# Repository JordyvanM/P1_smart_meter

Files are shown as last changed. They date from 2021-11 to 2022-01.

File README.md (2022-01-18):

# P1_smart_meter
This repository contains simulations, documentation and schematics on the P1 smart meter reader project.

# Table of Contents
## 1. [Simulations]
### ·[Two powersupply switching]
### ·[Opamp signal inverter]

## 2. [Documentation]
### ·[PVA Dutch] (plan of action)
### ·[Report]

## 3. [Software]

## 4. [PCB_project]

## 4. [Sources]
### [URLS]

[Two powersupply switching]: https://github.com/JordyvanM/P1_smart_meter/blob/main/Simulations/Two_powersupply_switch.asc
[Opamp signal inverter]: https://github.com/JordyvanM/P1_smart_meter/blob/main/Simulations/V1_3.3_inverter.asc
[Simulations]: https://github.com/JordyvanM/P1_smart_meter/tree/main/Simulations

[Documentation]: https://github.com/JordyvanM/P1_smart_meter/tree/main/Documentation
[PVA Dutch]: https://github.com/JordyvanM/P1_smart_meter/tree/main/Documentation/PVA
[Report]: https://github.com/JordyvanM/P1_smart_meter/tree/main/Documentation/Report

[Software]: https://github.com/JordyvanM/P1_smart_meter/tree/main/Software

[PCB_project]: https://github.com/JordyvanM/P1_smart_meter/tree/main/PCB_project

[Sources]: https://github.com/JordyvanM/P1_smart_meter/tree/main/Sources
[URLS]: https://github.com/JordyvanM/P1_smart_meter/blob/main/Sources/URLS.md

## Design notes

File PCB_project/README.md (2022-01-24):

When the [.zip] file is opened it can be extracted and opend in Altium Designer. The [Smart meter case.3mf] file contains the 3D file for the case of the PCB. This file can be downloaded and for example 3D printed.

[.zip]: https://github.com/JordyvanM/P1_smart_meter/blob/main/PCB_project/slimme_meter_V4%20(17-1-2022%2016-21-46).zip
[Smart meter case.3mf]: https://github.com/JordyvanM/P1_smart_meter/blob/main/PCB_project/Smart%20meter%20case.3mf

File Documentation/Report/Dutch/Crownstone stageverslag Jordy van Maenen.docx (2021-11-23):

Stageverslag Jordy van Maenen

# Opdracht 1: Slimme meter

# 1. Onderzoek

## 1.1 Algemeen:

De eerste opdracht van Crownstone is het ontwerpen van een product dat aangesloten (en gevoed) kan worden gebruik makend van de P1 poort van een slimme meter. In de P1 poort van een slimme meter kan een stekker van het type RJ11 6P4C of 6P6C gestoken worden. Op pin 1 van deze poort staat +5V en pin 6 is de power_GND pin. De voeding kan een stroom leveren van maximaal 250mA continu wanneer de slimme meter gebaseerd is op DSMR (Dutch Smart Meter Requirements) 5 of hoger [1]. Wanneer de slimme meter gebaseerd is op DSMR 4 of ouder kan er maximaal 100mA continu gebruikt worden [2]. Bij DSMR 2 kan er helemaal geen gebruik gemaakt worden van voeding vanuit de P1 poort. Exacte aantallen zijn niet beschikbaar maar DSMR 5 lijkt op dit moment de meest gebruikte standaard gevolgd door DSMR 4 en DSMR 2. DSMR 5 en 4 lijken erg op elkaar doordat gebruikt gemaakt wordt van dezelfde baudrate, een start bit, 8 data bits, geen parity bit en een stop bit. Er zijn echter wel een aantal verschillen als het gaat om de frequentie waarmee de verschillende standaarden hun informatie sturen. DSMR 5 verstuurt alleen elke seconde alle data en verstuurt dan de laatste 5 minuten meting van het gasverbruik, het thermische gebruik en watergebruik. DSMR 4 verstuurt elke 10 minuten alle data en verstuurt dan de laatste uur meting van het gasverbruik, het thermische gebruik en watergebruik. DSMR 2 verstuurt ieder uur alle data. Voor het versturen van de data maakt de slimme meter gebruik van een open collector uitgang. Dit houdt in dat de uitgang of floating of verbonden met GND is. Om hiermee een goed signaal te maken is een pull-up weerstand nodig.

## 1.2 Connector:

Om gebruik te maken van deze poort moet er een stekker in gestoken worden van het type RJ11 6P4C of 6P6C. Voor dit project is er gekozen om de RJ11 6P6C connector te gebruiken (ook wel de RJ12 connector genoemd). Deze connector heeft 2 pinnen meer dan de standaard RJ11 connector waardoor er gebruik gemaakt kan worden van de voeding vanuit de P1 poort.

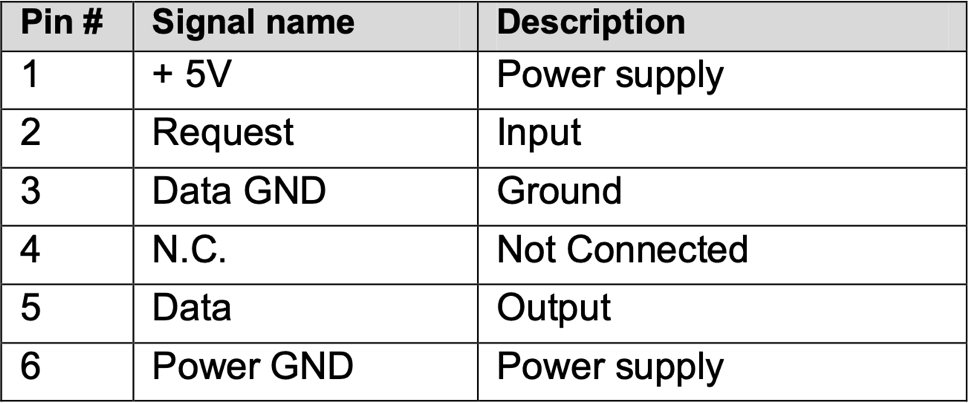
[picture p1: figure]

Figuur 1

In Figuur 1 is de pinout van de RJ12 connector weergegeven, deze tabel kan in de datasheets van DSMR 4 [2] en 5 [1] gevonden worden op pagina 6. Er mag maximaal 5mA de data pin in lopen. De voedingsspanning vanuit de P1 poort mag maximaal 5.5V zijn, om een maximale stroom van 5mA te realiseren is een weerstandswaarde van minimaal 5.5/5mA = 1100Ω nodig. De datalijn hoeft hoogstwaarschijnlijk geen 5mA te kunnen leveren om de rest van het circuit te laten functioneren dus is het handig om een nog hogere pull-up weerstand te gebruiken waardoor verliezen verminderd worden. Om de data overdracht te starten moet een spanning tussen de 4V en 5.5V op de request pin gezet worden.

## 1.3 Signaal P1 poort

Voor het ontwerp en het kiezen van een geschikte omvormer is het ook handig om te weten wat de maximale schakelsnelheid van het signaal uit de P1 poort is. Met een simpele schakeling bestaande uit een male RJ12 connector, een 6 kernige platte kabel, een pull-up weerstand en een prototypebordje kan dit onderzocht worden.

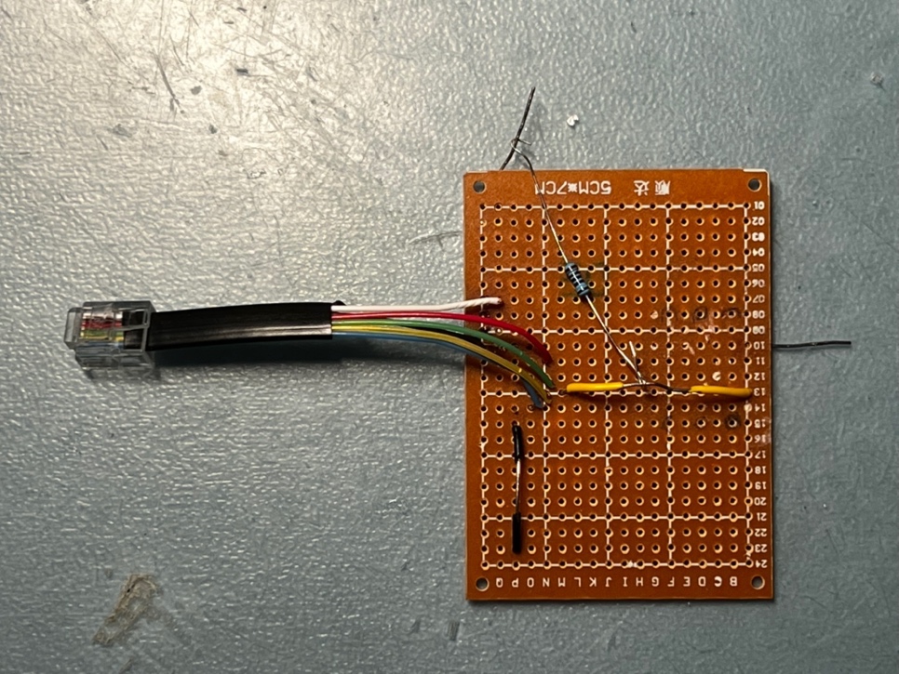
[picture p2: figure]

Figuur 2

Figuur 2 laat het ontworpen testbordje zien. De bovenste gestripte draad en de gestripte draad aan de rechterzijde moeten met elkaar verbonden worden om de dataoverdracht vanuit de P1 poort te starten. De gele in het midden gestripte draad is het meetpunt voor data pin 5. De zwarte in het midden gestripte draad is het GND punt. Dit bordje kan direct in de P1 poort van een slimme meter gestoken worden. Bij deze test is hij in een DSMR 5.0 meter gestoken om te onderzoeken wat de minimale puls duur is. Vervolgens is de probe van de oscilloscoop op de gele draad aangesloten en het GND punt op de zwarte draad. De oscilloscoop is aangezet en de twee volledig gestripte draden zijn met elkaar verbonden. Hierdoor werd op de oscilloscoop het signaal uit de P1 poort goed zichtbaar.

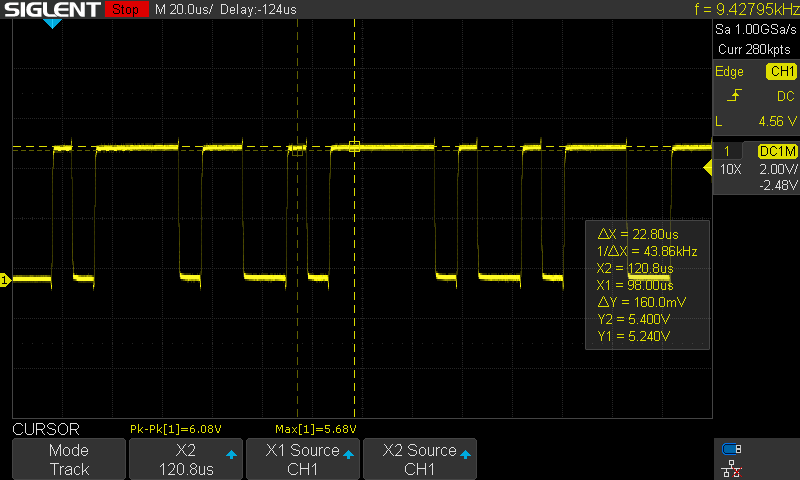
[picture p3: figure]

Figuur 3

Figuur 3 laat het signaal gemeten vanaf de half gestripte gele draad zien, dit is het signaal uit de P1 poort.

## 1.4 Omvormer

Het signaal uit de data pin is een geïnverteerd, te hoog maar voor de rest een voor de microcontroller leesbaar UART-signaal. Een hoge spanning (>1V, max 15V) is in dit geval dus een 0 en een lage spanning (<1V) is een 1. Om dit signaal leesbaar te maken voor de microcontroller moet het dus geïnverteerd en verlaagd worden tot maximaal 3.3V.

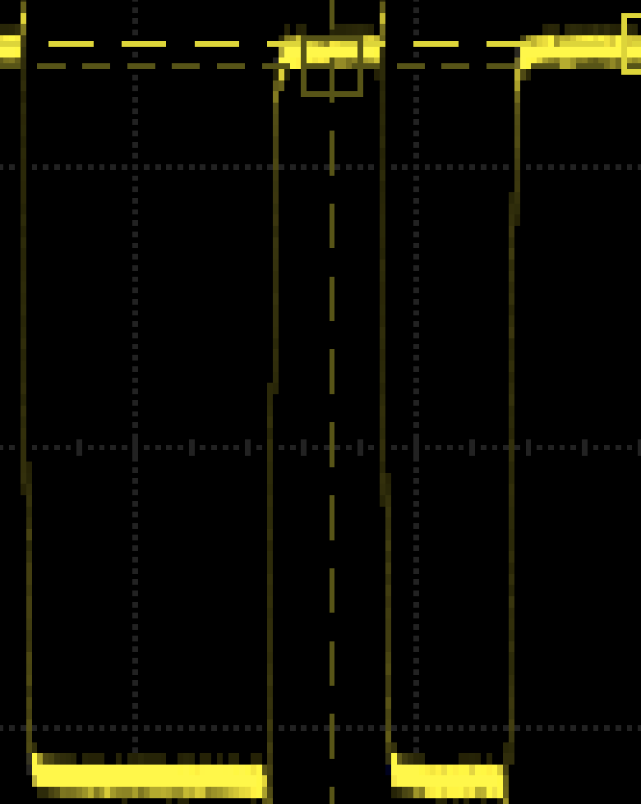
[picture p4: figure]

Figuur 4

Figuur 4 is een ingezoomd beeld van de kleinste puls duur uit Figuur 3. Deze puls duurt ongeveer 7.6us. Voor het kiezen van een geschikte omvormer is het van belang dat deze snel genoeg is om het signaal goed weer te kunnen geven. Om te bepalen welke slew rate nodig is om een signaal te krijgen waarvan maximaal 1/3 gebruikt wordt voor de rise en fall time zijn de volgende berekeningen nodig:

(7.6us)/6= 1.26us maximale rise time

(3.3v)/(1.26us)=2.62v/(us) minimale slew rate

Er is dus een minimale slew rate van 2.62 v/(us) nodig om een duidelijk signaal te behouden. Hier moet rekening mee gehouden worden wanneer de omvormer uitgekozen wordt.

## 1.5 Voeding

De voedingsspanning uit de P1 poort kan maximaal 5.5V en minimaal 4V zijn, over het algemeen is deze spanning 5V. Met het bordje in Figuur 2 is het ook mogelijk om de exacte voedingsspanning van de geteste slimme meter te meten.

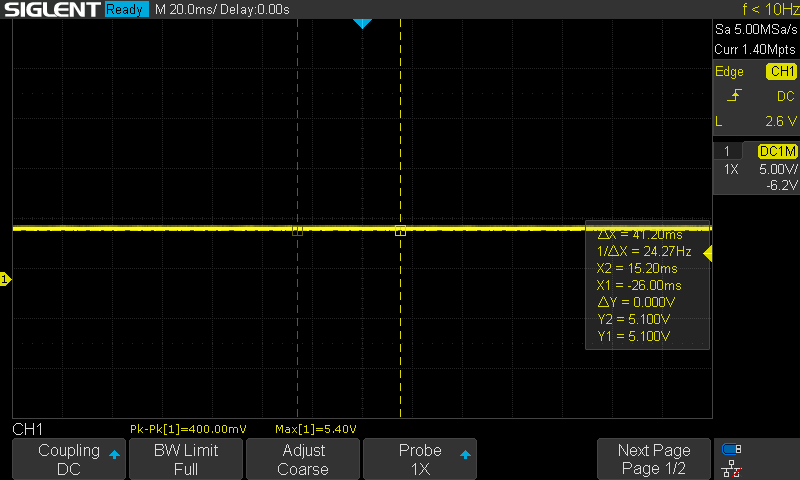
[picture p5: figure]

Figuur 5

Figuur 5 laat deze meting zien. Onderin is de maximaal gemeten spanning te zien, dit is 5.4V. Dit is waarschijnlijk een erg korte piek die door een storing van buitenaf komt. In het cursorvakje rechts in de afbeelding is Y2 en Y1 af te lezen. Dit zijn de gemeten spanningen op de cursors, beide zijn 5.1V. Deze meting laat zien dat de daadwerkelijke spanning erg in de buurt komt van de verwachtte 5V.

## 1.6 MCU

Voor de microcontroller unit zijn er verschillende mogelijkheden, er kan gebruik gemaakt worden van een kant en klare unit of van een eigen ontworpen schakeling met een losse NRF52832 chip. Een kant en klare module heeft als voordeel dat deze makkelijk te implementeren, al goedgekeurd en makkelijk te updaten is wanneer er een betere module beschikbaar komt. Het voordeel van een zelfontworpen schakeling is dat deze kleiner te maken is dan een kant en klare module en dat deze volledig aangepast kan worden aan de benodigdheden van het product. Daarnaast zijn de componentkosten lager zijn dan van een kant en klare module maar de ontwerpkosten hoger. Welk van de twee opties ook gekozen wordt, bij het ontwerp moet er aan een aantal zaken gedacht worden. Zo is er in het ontwerp een 32MHz oscillator en 32KHz oscillator nodig. Deze worden beide gebruikt voor timing in het huidige Crownstone product dus is het handig om deze ook in dit ontwerp te gebruiken. Verder moet er ook aan ontkoppelingscondensatoren gedacht worden. Deze zorgen ervoor dat de voedingsspanning geëgaliseerd wordt zodat de microcontroller geen instructies over gaat slaan of zich op een andere onverwachte manier gaat gedragen.

## 1.7 Software

Voor het verwerken van de informatie is ook goede software nodig. Het product moet idealiter kunnen werken met alle slimme meters die in gebruik zijn. Hierdoor zou het product aantrekkelijker zijn voor potentiele klanten omdat er niet nagedacht hoeft te worden of het apparaat wel geschikt is voor de gebruikte slimme meter. Dit zorgt alleen wel voor een aantal moeilijkheden. Zoals eerder beschreven zijn de verschillende standaarden wel degelijk verschillend van elkaar. Omdat bij DSMR 2 het voeden van externa apparaten door de P1 poort niet mogelijk is moet een manier gevonden worden om het product alsnog van voeding te zien willen de DSMR 2 meters ondersteund worden. Daarnaast moet het in software mogelijk gemaakt worden dat terwijl het programma draait de seriële instellingen vanzelf veranderd kunnen worden. Hierdoor zou de informatie uit DSMR 2 meters uitgelezen kunnen worden. Verder moet het programma ook in staat zijn om referentienummers te herkennen. Deze referentienummers geven aan wat de data die daarna komt betekent. Al deze referentienummers zijn te vinden in de DMSR 4 datasheet [2] en DSMR 5 datasheet [1]. De referentienummers gegeven in de datasheet zijn alle referentienummers, niet elke slimme meter gebruikt ze allemaal. Hierdoor moet het programma ook in staat zijn om nummers over te slaan wanneer deze niet gegeven worden. Bijvoorbeeld, een één fase slimme meter zal geen informatie geven over andere fasen dan degene waarop hij aangesloten zit.

## 1.8 Programma van eisen

Functionele eisen:

- Eis 1: Het eindproduct moet aangesloten kunnen worden op de P1 poort van een slimme meter.
- Eis 2: Het eindproduct moet gevoed kunnen worden door de P1 poort van een slimme meter.
- Eis 3: De actuele stroom en gasverbruik data uit deze poort dient verstuurd te worden via Bluetooth zodra deze ontvangen wordt vanuit de P1 poort.
- Eis 4: In het eindproduct dient er gebruik gemaakt te worden van de nRF52832 van Nordic Semi.
- Eis 5: Het eindproduct mag een maximale stroom van 100mA gebruiken.
- Eis 6: Het verbruik van meerdere fasen (indien aanwezig) moet individueel verzonden worden, het totaalverbruik kan dan op een aangesloten apparaat makkelijk berekend worden.
- Eis 7: Aan het begin van het bericht uit de P1 poort wordt een timestamp verstuurd. Deze dient door het eindproduct verzonden te worden.
- Eis 8: Het apparaat moet kunnen werken met slimme meters gebaseerd op Dutch Smart Meter Requirements (DSMR) 5, 4 en 2.

Niet functionele eisen:

- Eis 9: Het eindproduct moet zo goedkoop mogelijk uitgevoerd worden zonder dat andere eisen daaronder lijden.
- Eis 10: Het eindproduct moet zo klein mogelijk gemaakt worden zonder dat er op functionaliteit beperkt wordt.
- Eis 11: Het eindproduct moet via de SWD-pinnen geprogrammeerd kunnen worden.
- Eis 12: Het eindproduct moet UART gedebugd kunnen worden.

Verdere uitleg:

- Eis 1: Om ervoor te zorgen dat het eindproduct kan communiceren met de slimme meter moet het mogelijk zijn om het apparaat aan te sluiten op de slimme meter. Dit kan alleen door gebruik te maken van de P1 poort van de slimme meter.
- Eis 2: Slimme meters die gebruik maken van DSMR 4 of hoger kunnen externa apparaten voeden via de P1 poort. Het is handig om gebruik te maken van deze functie om het aansluiten van het eindproduct erg gemakkelijk te maken.
- Eis 3: Crownstone maakt in al haar producten gebruik van Bluetooth en ook dit eindproduct moet werken met Bluetooth zodat het geïntegreerd kan worden met de andere producten van Crownstone. De stroom en gasverbruik data is in het begin het meest interessant, hiermee kan al een goed inzicht verkregen worden in het energieverbruik. Extra informatie zoals standsverwarming en verkoeling of watergebruik kunnen later in software nog toegevoegd worden.
- Eis 4: Crownstone werkt op dit moment al met chips van Nordic Semi en onder andere ook de nRF52832. Voor het bedrijf is het daarom handig dat in dit eindproduct ook deze chip zit zodat de firmware van dit product geïntegreerd kan worden met de Bluenet firmware van Crownstone zelf. Deze firmware is te vinden op https://github.com/crownstone/bluenet.
- Eis 5: DSMR 5 en hoger kan tot 250mA maar in dit geval moet het stroomverbruik onder de 100mA blijven om ervoor te zorgen dat het eindproduct ook op meters gebaseerd op DSMR 4 werken zonder dat een externe voeding aangesloten hoeft te worden.
- Eis 6: Het verbruik van individuele fasen bekijken kan voor een gebruiker erg interessant zijn. Misschien worden de verschillende fasen bijvoorbeeld gebruikt voor verschillende delen van een gebouw, hier zou dan het verbruik van de verschillende delen van het gebouw gemonitord kunnen worden.
- Eis 7: Het is handig om de timestamp uit de P1 poort te versturen zodat het gemeten energieverbruik op het correcte tijdstip weergegeven wordt.
- Eis 8: Het is handig om het eindproduct te kunnen laten werken op vrijwel alle slimme meters in Nederland. Hierdoor hoeven potentiële klanten niet na te denken of het eindproduct wel of niet op hun slimme meter werkt.
- Eis 9: Voor het maken van dit prototype moet er nagedacht worden over de kosten. Het is niet de bedoeling dat er roekeloos materialen ingekocht worden terwijl er misschien met een klein beetje nadenken een goedkoper alternatief gevonden kan worden.
- Eis 10: Voor de gebruiker is het handig om dit product zo klein mogelijk te maken. Hierdoor zou het eindproduct makkelijker in krappe ruimtes geplaatst kunnen worden.
- Eis 11: De SWD pinnen op de nRF52832 zijn er om de nRF52832 te programmeren. Deze moeten makkelijk beschikbaar zijn voor het programmeren van de nRF52832.
- Eis 12: UART wordt door Crownstone gebruikt voor het debuggen. Het is handig om deze functie ook toe te voegen aan het te maken eindproduct zodat de programmeurs zo min mogelijk hoeven te veranderen in hun manier van programmeren.

# 1 Keuzes

Om dit product werkend te krijgen zijn er meerdere deelsystemen nodig. Een connector, een omvormer, een voeding en een MCU-module. Verder moeten er ook nog andere keuzes gemaakt worden die de werking van het product beïnvloeden.

## 2.1 Connector

Het product moet aangesloten kunnen worden op een slimme meter, dit gebeurt met een RJ12 (RJ11 6p6c) connector. Er kan gekozen worden om het product te voorzien van een RJ12 poort zodat er een male RJ12 naar male RJ12 kabeltje gebruikt kan worden. Een andere optie is om een kabel met aan één kant een male RJ12 stekker aan de andere kant vast te solderen op het product. Dit zou ervoor zorgen dat het product een stuk platter kan worden maar heeft als nadeel dat de productie meer kost en dat wanneer het kabeltje kapotgaat het hele product niet meer werkt.

Oplossing | Voordelen | Nadelen
RJ12 poort op PCB solderen | Goedkoop, voorkomt onnodig onbruikbaar raken van het product. | Maakt het ontwerp een stuk groter
RJ12 kabel op PCB solderen | Klein ontwerp | Duur, moeilijke assemblage

Figuur 6

Conclusie:

Er is voor gekozen om in het ontwerp gebruik te maken van de RJ12 poort op de PCB. Het ontwerp zal desondanks de grote connector erg klein blijven.

## 2.2 Omvormer

Een omvormer is nodig om ervoor te zorgen dat het te hoge en geïnverteerde UART-signaal leesbaar te maken voor de microcontroller. Hiervoor zijn verschillende opties mogelijk. Er kan gebruik gemaakt worden van een opamp. Hierbij zal 3.3 volt op de positieve voeding gezet worden en de negatieve kant van de voeding aan GND aangesloten worden. Op de positieve ingang zal 1.65V volt gezet worden en op de negatieve ingang zal het signaal vanuit de P1 poort gezet worden. De 1.65V zal behaald worden door gebruik te maken van twee weerstanden van 1MΩ en deze als spanningsdeler te laten fungeren. Hierdoor zal de uitgang van de opamp laag zijn wanneer het signaal uit de P1 poort hoger is dan 1.65 volt en 3.3 volt zijn wanneer het signaal uit de P1 poort lager is dan 1.65 volt.

Een andere optie is het gebruiken van een transistorschakeling. Hiermee zou de schakeling uit alleen transistoren en weerstanden bestaan. Dit heeft als voordeel dat het goedkoper in onderdelen is. Nadelen zijn alleen dat er actief een stroom in moet gaan lopen om een spanning te krijgen. In het ideale geval zou dit bij een opamp niet het geval zijn.

Oplossing | Voordelen | Nadelen
Opamp | Het is één component dat zowel de spanning verlaagt als inverteert. Makkelijk te fabriceren. Blijft snel schakelen 3.3V onder een load. | Duurder
Transistor en weerstanden | Goedkoop | Output komt niet bij GND. Gevoeliger voor temperatuur. Meer componenten dus meer solderen.

Figuur 7

Conclusie:

Er is gekozen om in het ontwerp gebruik te maken van een opamp. Hier is gemak en accuraatheid belangrijker.

## 2.3 Voeding

Een voeding zorgt ervoor dat de spanning die het product in gaat geschikt is om gebruikt te worden door de individuele componenten. Hiervoor zijn er meerdere opties beschikbaar, een LDO of een schakelende voeding. Een LDO heeft als voordeel dat het erg eenvoudig te implementeren is, zeker wanneer er gekozen wordt voor een LDO met een gefixeerde uitgangsspanning. Het nadeel van een LDO is dat er meer vermogen verspild wordt in de vorm van warmte dan bij een schakelende voeding. Een schakelende voeding heeft als voordeel dat hij erg zuinig is. Nadelen van een schakelende voeding zijn dat hij meer ruis veroorzaakt, lastiger te implementeren is en duurder is.

Oplossing | Voordelen | Nadelen
LDO | Makkelijk en goedkoop | Minder efficiënt
Schakelende voeding | Energiezuinig | Duurder, meer componenten, meer ruis.

Figuur 8

Conclusie:

Er is gekozen om in het ontwerp gebruik te maken van de LDO. Deze zijn wel minder efficiënt alleen het stroomverbruik van het gehele ontwerp zal minimaal zijn dus ook de verspilling.

## 2.4 MCU-module

De MCU-module is nodig om alle binnenkomende informatie te verwerken en daarop te reageren. Deze module moet programmeerbaar zijn zodat er eigen software op gezet kan worden. Als microcontroller wordt de NRF52832 gebruikt. Er zijn alleen verschillende manieren om deze microcontroller te implementeren, dit kan in de vorm van een kant en klare module of een zelfontworpen module. Het voordeel van een kant en klare module is dat deze makkelijk te implementeren zijn en makkelijk te vervangen zijn wanneer er van een andere microcontroller gebruikgemaakt wil worden. Het voordeel van een zelfontworpen module is dat de kosten van de componenten lager zijn en dat de schakeling op een eigen PCB erg klein gemaakt kan worden.

Oplossing | Voordelen | Nadelen
Kant en klare module | Makkelijk te implementeren, makkelijk te upgraden. | Prijs van de component ligt hoger dan de losse componenten van een zelfontworpen module.
Zelfontworpen module | Kan erg klein gemaakt worden, goedkoper in de ontwikkeling. | Het ontwerpen is lastig, tijdrovend en daardoor duur. Wanneer een nieuwe microcontroller uit komt moet de gehele pcb herontworpen worden.

Figuur 9

Conclusie:

Er is gekozen om in het ontwerp gebruik te maken van een kant en klare module. De aanschaf kosten worden uiteindelijk overschaduwd door de ontwerpkosten van een zelfontworpen module.

## 2.5 Wel of geen externe voeding nodig

Volgens de als eerst opgestelde eisen moet het te ontwerpen product in ieder geval gevoed kunnen worden vanuit de P1 poort. Na verder onderzoek is er alleen ontdekt dat oudere slimme meters niet de mogelijkheid hebben om externe apparatuur via de P1 poort te voeden. Deze oudere slimme meters worden in ieder geval niet meer geplaatst maar zijn nog wel in gebruik. Exacte hoeveelheden zijn ook via de energieleveranciers lastig te krijgen. Wanneer er in het ontwerp geen mogelijkheid meegenomen wordt om het product via bijvoorbeeld een micro USB-poort te voeden zullen de oudere slimme meters van DSMR-versie 2 of lager niet ondersteund worden.

Oplossing | Voordelen | Nadelen
Geen externe voedingsmogelijkheid | Makkelijker te ontwerpen, goedkoper in productie, makkelijker in code te implementeren | Het product zal niet op oudere slimme meters werken, werkt dan op minder slimme meters dan de concurrentie
Wel een externe voedingsmogelijkheid | De consument hoeft niet na te denken wat voor slimme meter er geïnstalleerd is | Hogere implementatiekosten, hogere productiekosten

Figuur 10

Conclusie:

Er is gekozen om in het ontwerp wel de mogelijkheid om het product extern te voeden toe te voegen. Hierdoor hoeft de consument niet na te denken of dit product wel in zijn of haar specifieke situatie werkt. Wanneer dit niet mogelijk zou zijn zou er een extra reden zijn om voor een concurrerend product te kiezen.

## 2.6 LED’s

Voor het geven van visuele indicatoren richting de gebruiker zijn LED’s erg handig. Met verschillende kleuren kan bijvoorbeeld aangegeven worden dat het product aan staat en dat er bijvoorbeeld dataoverdracht is. Er zijn alleen verschillende manieren om LED’s te implementeren. Er kan gekozen worden voor losse LED’s direct op de voedingsspanning en datalijn aangesloten met aan/uit controle van de microcontroller waarmee hardware matig aangegeven wordt dat het product aan staat en dat er dataoverdracht is. De microcontroller heeft op deze manier wel nog de controle of dat LED’s aan of uit staan maar deze kunnen niet snel geschakeld worden door middel van PWM. Een andere keuze is om een RGB LED op de microcontroller aan te sluiten en softwarematig statusindicatoren te geven. De eerste optie heeft als voordeel dat het erg makkelijk te implementeren en goedkoop is, het nadeel is alleen dat deze LED’s later niet een andere functie gegeven kan worden. De laatste optie heeft als voordeel dat de functie van de LED’s later nog veranderd kan worden, het nadeel is dat er iets meer code nodig is en dat er Mosfets nodig zijn om de LED’s te schakelen.

Oplossing | Voordelen | Nadelen
Losse LED’s direct op signaallijnen | Makkelijker te ontwerpen, goedkoper in productie, minimale hoeveelheid code nodig | De LED’s hebben maar één functie en die kan later ook niet aangepast worden
RGB LED met microcontroller aansturen | Softwarematig de functies aanpassen van de LED’s | Meer componenten nodig

Figuur 11

Conclusie:

Er is gekozen om een RGB-led met behulp van Mosfets op de microcontroller aan te sluiten. Het is iets duurder maar brengt wel veel meer mogelijkheden met zich mee.

# 3. Het ontwerp

## 3.1 Componentkeuze

Onderdeel | Componenten | Verschillen | Keuze
RJ12 connector | 1. Molex 95501-6669 [3] 2. Wurt Elektronik 615006138421 [4] | Optie 1 is beter leverbaar en compacter dan optie 2. | Er is gekozen om van optie 1 gebruik te maken in het uiteindelijke ontwerp.
Opamp | 1. TI TLV9101IDBVR [5] | Optie 1 heeft een rail-to-rail input en output en een slew-rate van 4.5V/µs. | Er is gekozen om van optie 1 gebruik te maken in het uiteindelijke ontwerp.
LDO | 1. TI TPS7A2533DRVR [6] 2. ST LDFM33PVR [7] 3. MT MCP1755S-3302E/MC [8] | Optie 1 heeft de laagste ruststroom van maar 2µA, is per 1000 stuks de één na goedkoopste maar de duurste in kleine hoeveelheden. Optie 2 is de goedkoopste per 1000 stuks en de één na goedkoopste in kleine hoeveelheden, deze heeft alleen de hoogste ruststroom van 200µA. Optie 3 is in kleine hoeveelheden het goedkoopst maar per 1000 stuks het duurste, deze zit op het gebied van ruststroom tussen de andere twee in met 68µA | Er is gekozen om van optie 1 gebruik te maken in het uiteindelijke ontwerp.
MCU-module | 1. Raytac MDBT42Q-512KV2 [9] 2. Aconno ACN52832 [10]

Figuur 12

- Voor de female RJ12 connector is er voor de 95501-6669 connector van Molex gekozen. Deze connector is uit voorraad leverbaar en is grotendeels SMD. Hierdoor kunnen er wanneer nodig meer componenten aan de onderkant geplaatst worden.
- Voor de als omvormer gebruikte opamp is er gekozen voor de TLV9101IDBVR van TI. Dit is een low power rail-to-rail opamp, hierdoor is de output zo dicht mogelijk bij 3.3V of GND.
- Voor de voeding is er gekozen voor een TPS7A2533DRVR van TI. Deze LDO heeft een Ultra-low quiescent current van 2 μA en een maximum dropout voltage van minder dan 340 mV bij 300 mA waardoor het een erg zuinige LDO is. Deze LDO geeft ook standaard 3.3V zonder dat daarvoor externe weerstanden nodig zijn. Dit scheelt ruimte op de PCB en kan de spanning niet kan veranderen door in temperatuur veranderende weerstanden.
- Voor de MCU-module is er gekozen voor een ACN52832 van Oconno. Deze module is goed voorradig, en is makkelijk te implementeren. Alle pinnen zitten aan de buitenkant wat het solderen en debuggen een stuk makkelijker maakt. Deze module is ook te vinden op de website van Nordic Semi [11].
- Als connector voor een externe voeding is er gekozen voor een micro-USB poort. Deze poort is wel al behoorlijk op leeftijd alleen ze zijn goedkoop om te implementeren en zijn er al veel geschikte kabels en adapters op de markt. USB geeft standaard ook een spanning van +5V, dit is dezelfde spanning als uit de P1 poort. Dit versimpelt het ontwerp ook ten opzichte van wanneer er een andere poort gekozen zou zijn.
- Er is gekozen om een 2x5 2.54mm smd footprint te gebruiken voor het debuggen. Deze connector wordt op dit moment ook op het hoofdproduct van Crownstone gebruikt voor het debuggen en programmeren. Het gebruiken van dezelfde connector maakt het debuggen en programmeren van het te ontwerpen product voor het bedrijf een stuk makkelijker.
- Voor de RGB-led is er gekozen voor de L1MC-RGB0035000MP0 van Lumileds. Deze RGB-led is goed uit voorraad leverbaar, is meer dan fel genoeg en goedkoop.

## 3.2 Ontwerp units

Hieronder zal uitgelegd worden hoe de hierboven benoemde componenten geïmplementeerd zullen worden in de verschillende units en waarom ze op die manier geïmplementeerd worden.

### 3.2.1 RJ12 connector

Pin 3(data_gnd) zal aan pin 6(power_gnd) verbonden worden, het is niet nodig dat de data een afzonderlijke ground heeft. Pin 4 is NC dus blijft floating. Pin 5 is de data pin, deze pin is een open collector uitgang. Om uit deze uitgang een nuttig signaal te krijgen is een pull-up weerstand nodig. Volgens hoofdstuk 4.6 van de datasheet van DSMR 4.2 [2] en hoofdstuk 5.8 van DSMR 5,0 [1] mag er door het apparaat dat aan de P1 poort aangesloten zit maximaal 5mA geleverd kunnen worden aan de data pin. Zoals in hoofdstuk 1 benoemd is er minimaal een weerstand van 1100Ω nodig om deze maximale stroom te realiseren. Er is alleen gekozen voor een hogere weerstand van 10KΩ om de stroom te beperken tot 0.55mA en zo verspilling te verkleinen. Deze 10KΩ pull-up weerstand zal aan pin 2(request) verbonden worden zodat de data uit pin 5 leesbaar is wanneer de data opgevraagd wordt.

Pin 1(+5V) en pin 2(request) zullen aan een later genoemde schakeling gekoppeld worden. Figuur 13 laat de hierboven uitgelegde informatie schematisch zien. J1 is hier de RJ12 connector. Zoals later in dit hoofdstuk ook gezien zal worden wordt er vaak gebruikgemaakt van 0603 weerstanden en condensatoren. Er is voor dit formaat gekozen omdat dit formaat erg klein maar nog wel met de hand te solderen is. Verder zijn er van dit formaat al veel weerstanden en condensatoren op voorraad wat relatief veel verschil maakt in de inkoopkosten omdat deze vervolgens niet meer in kleine hoeveelheden besteld hoeven te worden.

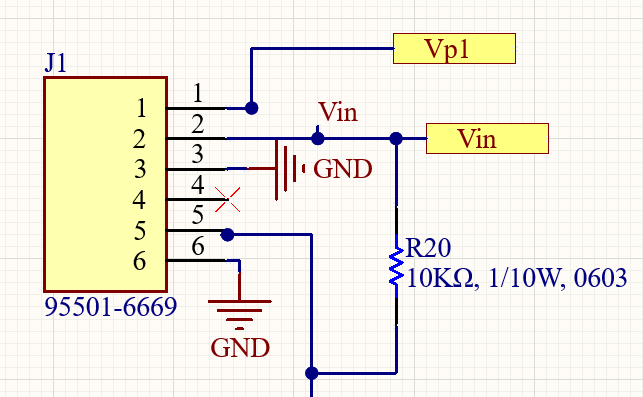
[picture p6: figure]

Figuur 13

### 3.2.2 Voeding

De micro USB-poort heeft meerdere shield pinnen. Het wordt aangeraden om deze aan ground te verbinden, in dit ontwerp is dat niet noodzakelijk omdat er geen data vanuit de micro USB-poort gehaald zal worden maar het is alsnog nuttig omdat dit de connectie op de PCB verstevigt. Van deze poort zullen alleen de GND en VBUS-pin gebruikt worden om te dienen als externe voeding.

Omdat er gekozen is om het te ontwerpen product zowel via de P1 poort te kunnen voeden als via een externe voeding is er een schakeling nodig die tussen deze twee bronnen schakelt. De bedoeling is dat wanneer de externe voeding in het product gestoken wordt dat er stroom uit deze bron gebruikt wordt en niet vanuit de P1 poort onafhankelijk of dat de P1 poort de stroom kan leveren. Ook mag het niet mogelijk zijn dat er stroom één van de voeding in loopt, hierdoor kunnen de voedingen beschadigd raken.

Een optie zou zijn om beide voedingsbronnen met twee diodes aan elkaar te koppelen, hierdoor kan er geen stroom de voedingen in lopen. Het nadeel is alleen dat met dit systeem alle stroom gebruikt wordt van de voeding met de hoogste spanning. Dit is natuurlijk niet de bedoeling, wanneer een klant een externe voeding in het apparaat steekt moet deze voeding wel gebruikt worden.

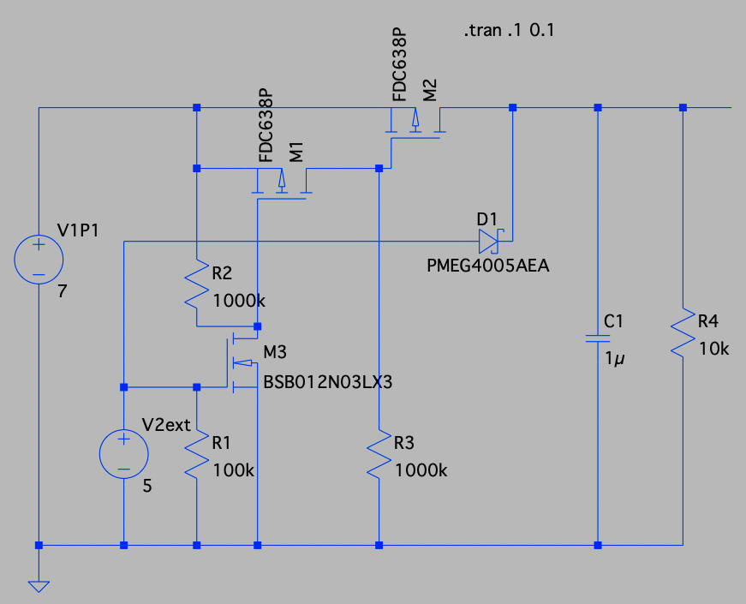
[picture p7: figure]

Figuur 14

Een tweede optie is de in Figuur 14 weergegeven schakeling. Wanneer de externe voeding niet aangesloten zit is N-mosfet M3 laag getrokken. Deze mosfet zorgt dat P-mosfet M1 hoog getrokken wordt waardoor deze niet in geleiding gaat. Vervolgens wordt P-mosfet M2 laag getrokken waardoor deze wel in geleiding gaat en de voedingsspanning vanuit de P1 poort doorlaat. Wanneer de externe voeding wel aangesloten zit wordt M3 hoog getrokken waardoor deze in geleiding gaat, vervolgens M1 laag trekt en deze ook in geleiding gaat waardoor M2 hoog getrokken wordt en niet in geleiding gaat. Hierdoor heeft de externe voeding altijd voorrang. De externe voeding heeft alleen een spanningsval over diode D1, dit is niet erg omdat de externe voeding minimaal 5 volt is en er in de rest van de schakeling alleen 3.3V gebruikt wordt. Voor deze diode wordt de PMEG3020EP,115 van Nexperia gebruikt. Er is voor deze schottky diode gekozen omdat deze een erg lage voorwaartse spanning van 310mV heeft. Door deze lage voorwaartse spanning worden vermogensverliezen vermindert. In dit schema simuleert R4 de load, deze weerstand zal dus niet aanwezig zijn in het uiteindelijke ontwerp. Voor de N-channel Mosfet wordt er gebruik gemaakt van de NX3020NAK,215, dit is een low power Mosfet. Voor de P-channel Mosfet wordt de NX3008PBKW,115,LF gebruikt. Van deze Mosfet zullen er twee gebruikt worden in de schakeling. De N-channel Mosfet heeft een Rds on van 4,5 Ohm en de P-channel Mosfet een Rds on van 4,1 ohm. Dit is in beide gevallen erg weinig waardoor de verspilling minimaal is.

De uitgang van de in Figuur 14 weergegeven schakeling zal vervolgens aan pin 2 van de RJ12 poort gekoppeld worden. Hierdoor staat er altijd een spanning op de request pin hoger dan de minimaal benodigde 4 Volt. Hierdoor zal de P1 poort altijd data gaat zenden wanneer het te ontwerpen product aangesloten is en een voeding heeft. De uitgang van de hierboven weergegeven schakeling zal ook op de ingang van de LDO aangesloten worden. Figuur 15 laat het in Figuur 14 weergegeven schema nog een keer zien met hierbij exact de te gebruiken componenten.

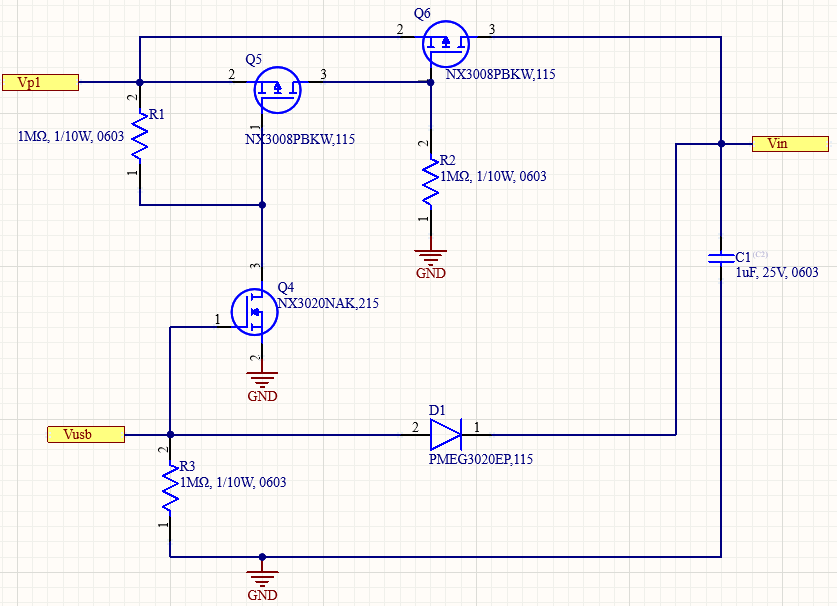
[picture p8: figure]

Figuur 15

### 3.2.3 Signaalomvormer

Voor de signaalomvormer wordt de opamp gebruikt als comparator, in Figuur 16 is de gebruikte schakeling te zien. De positieve kant van de voeding wordt aangesloten op de 3.3V van de uitgang van de LDO en de negatieve voedingskant wordt aangesloten op GND. Op de positieve kant wordt via een spanningsdeler met twee keer een 1M ohm weerstand de 3.3V verlaagd naar 1.65V. Op de negatieve kant wordt het signaal vanuit de P1 meter aangesloten. De spanningsdeler is nodig om ervoor te zorgen dat de opamp niet twee signalen met elkaar hoeft te vergelijken die beiden minimaal gelijk zijn aan de voedingsspanning. Dit zou ervoor zorgen dat de output van de opamp onvoorspelbaar zou worden.

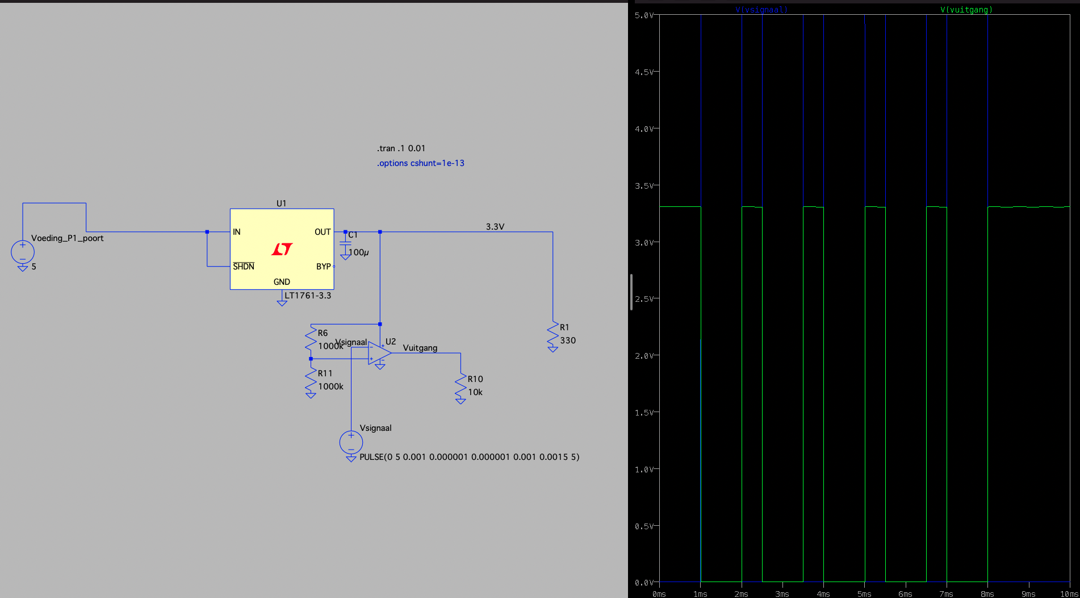
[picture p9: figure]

Figuur 16

Figuur 17 laat het te gebruiken schema nogmaals zien maar nu met de juiste componenten.

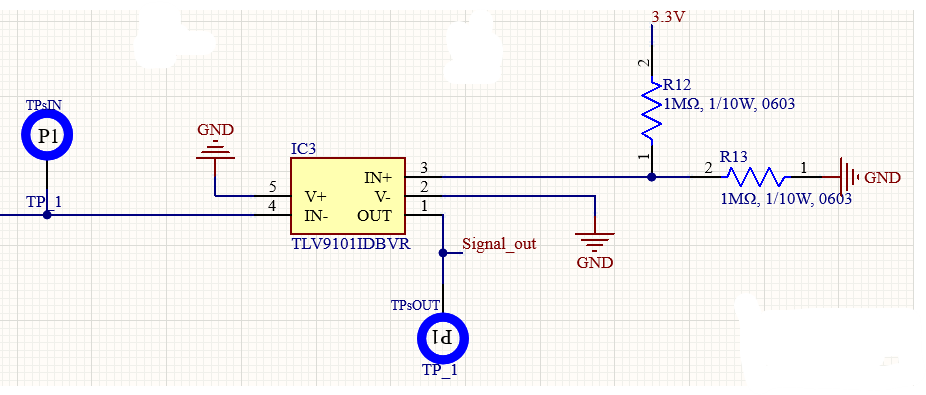
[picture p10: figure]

Figuur 17

### 3.2.4 Spanningsomvormer

Aan de LDO is een 1uF condensator op de ingang en een 2.2uF condensator op de uitgang geplaatst. Deze condensatorwaarden worden aangeraden door de datasheet, er wordt ook rekening gehouden met de gemiddelde degradatie en afwijking van de condensatoren. Deze LDO beschikt ook over een “power good” pin. Deze pin wordt in dit ontwerp niet gebruikt en de datasheet raadt dan aan om deze aan GND te koppelen voor een verbeterde warmte dissipatie. Ditzelfde geldt voor de NC pin, deze pin heeft helemaal geen functie maar ook hiervan wordt aangeraden om deze aan GND te koppelen. De enable pin wordt direct aan de ingang gekoppeld zodat de LDO altijd werkt wanneer er een spanning op de ingang staat.

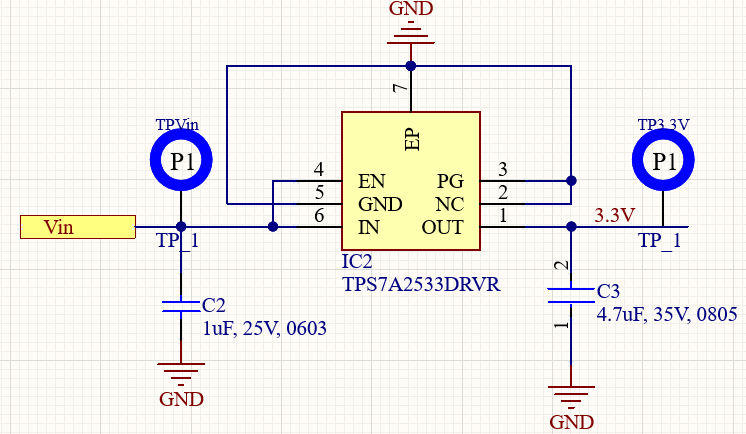
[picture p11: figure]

Figuur 18

### 3.2.5 MCU

Aan de ACN52832 module zullen alle deelsystemen uiteindelijk gekoppeld worden. Voor het debuggen wordt er gebruik gemaakt van de 2x5 2.54mm smd footprint. De pinnen van deze footprint zijn op dezelfde manier aan de NRF52832 gekoppeld als dat nu gedaan is in het huidige Crownstone product. Hierdoor hoeft er in de code zo min mogelijk veranderd te worden voor het confituren van deze pinnen. Deze footprint heeft daarnaast ook als voordeel dat er male-headers op gezet kunnen worden. Dit maakt het programmeren en debuggen een stuk eenvoudiger.

Figuur 19 laat de MCU-unit en alle verbindingen daaraan goed zien.

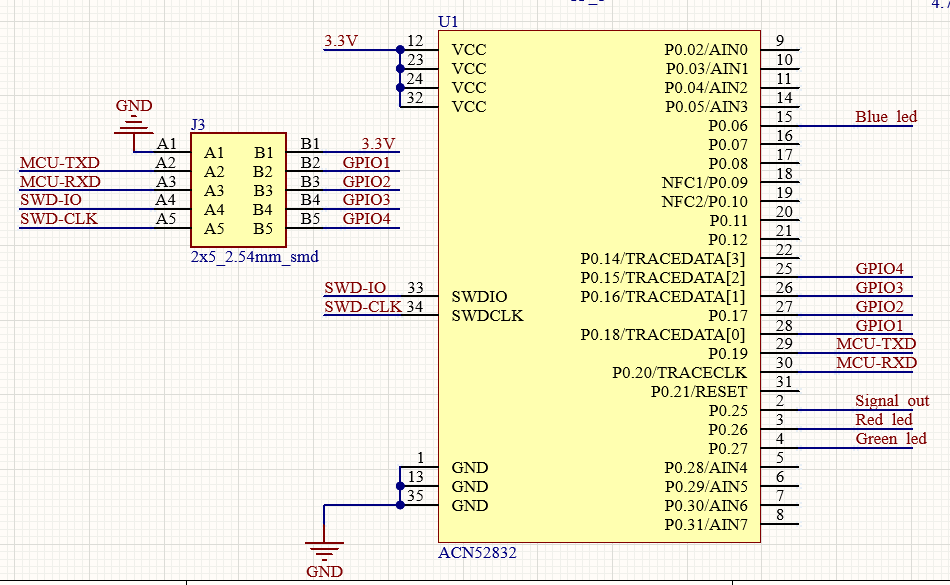
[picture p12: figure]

Figuur 19

### 3.2.6 LED’s

Voor het schakelen van de gekozen RGB-led is er gekozen om gebruik te maken van de NX3020NAK,215 n-channel Mosfet. Deze Mosfet heeft een lage ingangscapaciteit van 20pF maximaal. Deze Mosfet is al eerder in een grote hoeveelheid besteld waarmee kosten van het klein inkopen bespaard blijven. Tussen de GPIO-pin van de microcontroller en de Mosfet is nog een weerstand van 4.7K ohm geplaatst. Deze weerstand zorgt ervoor dat de momentane stroom beperkt wordt en de microcontroller bij snel schakelen niet beschadigd raakt. De NRF52832 kan bij een voedingsspanning van 3.3V ongeveer 25mA afvoeren en nog minder dan dat voeden vanuit de GPIO pinnen (in theorie is de sink en source current gelijk, de NRF heeft alleen meer GND dan Vdd pinnen waardoor afgeraden wordt om 25mA te voeden vanuit de GPIO pinnen). Figuur 20 is afkomstig uit de datasheet van de NRF52832. De weergegeven stromen zijn alleen maximumwaarden dus het is niet verstandig om een PWM-signaal te generen die die stroom moet kunnen leveren. In Figuur 21 zijn 10 cycli van een PWM-signaal met een duty cycle van 50% te zien. Met deze schakelsnelheid wordt een frequentie van 1/(0.2 × 10^(-3)) × 10 =50Khz gemakkelijk behaald, dit is meer dan voldoende.

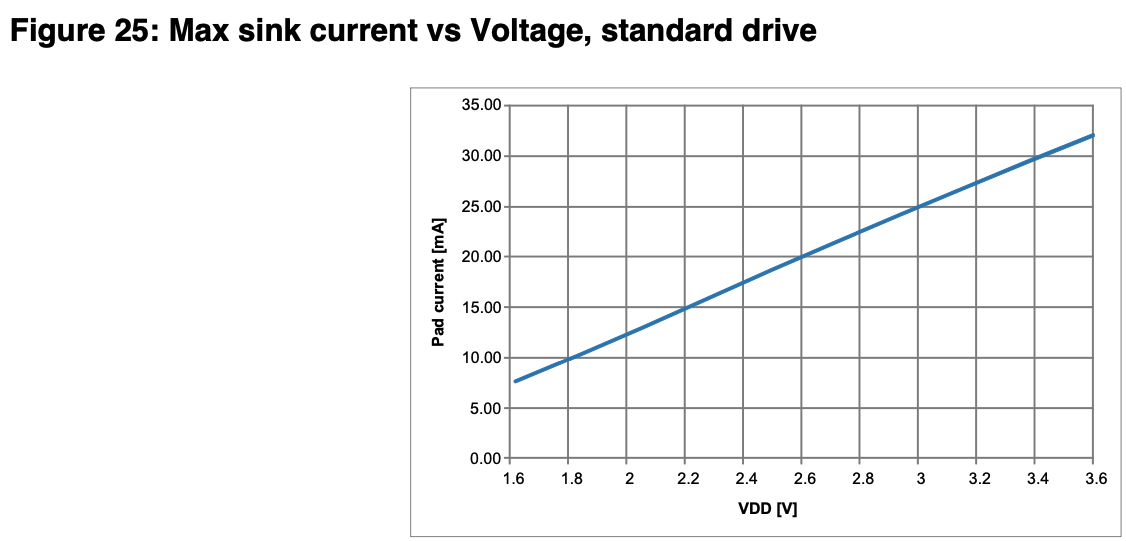
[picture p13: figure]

Figuur 20

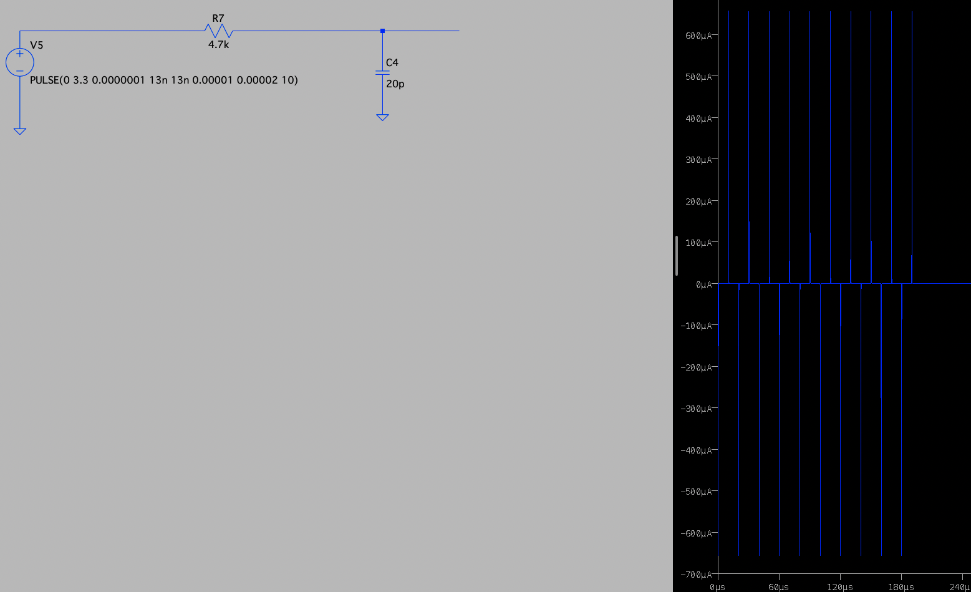
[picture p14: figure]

Figuur 21

In serie met de opamp en LED’s is ook nog een weerstand nodig om de stroom te beperken. Deze weerstand kan uitgerekend worden met de volgende formule:

Rs = (Vs-Vf)/(If)

Hier is Rs de benodigde weerstandswaarde, Vs is de voedingsspanning, Vf is de spanningsval over de LED en If is de maximale stroom door de LED.

De gekozen RGB LED heeft over de verschillende kleuren LED’s een andere spanningsval, de maximale stroom door elk van de LED’s is 20mA. De rode LED heeft een spanningsval van 2.1V, de groene LED van 2.8V en de blauwe LED van 3.0V. De RDSon van de Mosfet ligt tussen de 3Ω en 13Ω. Deze weerstand staat dus ook nog in serie met de LED. Voor het kiezen van de weerstandswaarde is het handig om uit te gaan van een lage RDSon zodat er alleen maar minder stroom kan lopen en niet meer. Er is voor gekozen om de stroom te beperken tot 15mA max, hierdoor zal de LED niet snel kapotgaan. Er is dan voor de rode LED een weerstand nodig van:

Rsr= (3.3-2.1)/(15 × 10^(-3))=80Ω

Voor de groene LED een weerstand van:

Rsg= (3.3-2.8)/(15 × 10^(-3))=33.3Ω

Voor de blauwe LED een weerstand van:

Rsb= (3.3-3.0)/(15 × 10^(-3))=20Ω

Van deze waarde wordt de minimale RDSon van de Mosfet afgehaald, Rsr = 80 – 3 = 77Ω,

Rsg = 33.3 – 3 = 30.3Ω en Rsb = 20 – 3 = 17Ω. De beschikbare weerstanden die hiervan in de buurt komen zijn: Rsr = 82Ω, Rsg = 33Ω en Rsb = 18Ω.

In dit ontwerp wordt driemaal de NX3020NAK,215 n-channel Mosfet gebruikt voor het schakelen van de LED’s.

Figuur 22 laat de hierboven uitgelegde schakeling zien met de connecties naar de MCU-unit.

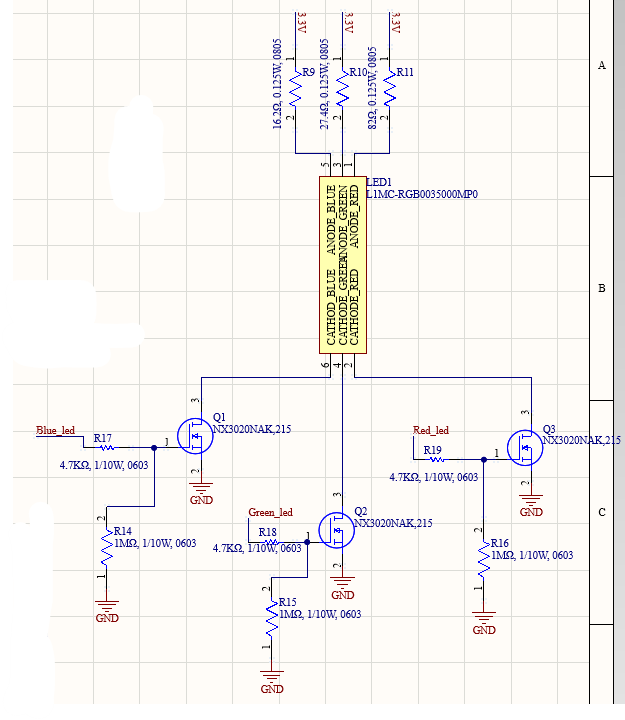
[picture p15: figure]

Figuur 22

### 3.2.7 Overig

Naast alle losse units zijn er ook nog andere delen ontworpen. Een ander onderdeel zijn de testpunten. Testpunten zijn erg belangrijk omdat hiermee makkelijk verschillende spanningen in de PCB gemeten kunnen worden terwijl de PCB al volledig gefabriceerd is. De blauwe cirkels met daarin P1 die te zien zijn in eerdere figuren stellen de gebruikte testpunten voor. Er is gekozen om een testpunt te zetten op de 3.3V, het ingangssignaal van de signaalomvormer, het uitgangssignaal van de spanningsomvormer, de ingangsspanning van de spanningsomvormer en GND.

# 4. Unittests

In dit hoofdstuk zullen de verschillende unittests beschreven worden en zullen wanneer uitgevoerd de testresultaten er direct onder gezet worden.

## 4.1 RJ12 connector

Deze test is makkelijk uit te voeren maar is wel belangrijk. Wanneer er intern een connectie verbroken is zou het wanneer geïntegreerd met de rest van het systeem erg lang duren voordat er ontdekt wordt dat de connector kapot is.

### 4.1.1 RJ12 connector test

Benodigdheden | - Multimeter
Stappen | - Stap 1: Zet de multimeter op de doorpiep functie. - Stap 2: Meet of dat elk van de pinnen aan de onderkant van de connector verbonden is met de pinnen aan de binnenkant van de connector.
Voltooid | Wanneer er bij de laatste stap geen problemen gevonden worden is de test met succes afgerond.

Figuur 23

### 4.1.2 Testresultaat RJ12 connector

Deze test is geslaagd, elke van de pinnen aan de binnenkant is verbonden aan de juiste pin aan de onderkant.

## 4.2 Voeding

Het is belangrijk dat de voeding eerst als individueel systeem getest wordt. Wanneer deze pas getest zou worden bij het integreren zouden er door een niet functionerende voeding andere systemen beschadigd kunnen raken.

### 4.2.1 Voeding test

Benodigdheden | - Dubbele labvoeding - Oscilloscoop - Multimeter

Stappen

- Stap 1: Zet beide kanten van de labvoeding op 5V met een stroomlimiet van 250mA
- Stap 2: Zet de multimeter op stroom meten
- Stap 3: Zet de multimeter in serie met de uitgang van de linker kant van de voeding
- Stap 4: Sluit de linker kant van de voeding met de multimeter in serie aan op de P1 ingang van de schakeling
- Stap 5: Sluit de rechter kant van de voeding aan op de micro-USB kant van de schakeling.
- Stap 6: Sluit de oscilloscoop aan op de uitgang van de schakeling
- Stap 7: Sluit een weerstand van 56 ohm aan op de uitgang, deze weerstand simuleert de load van de rest van het circuit
- Stap 8: Zet de linker kant van de voeding aan en kijk op de oscilloscoop of de spanning minimaal 4.5V betreft
- Stap 9: Zet de rechter kant van de voeding aan en kijk op de oscilloscoop of de spanning minimaal 4.1V betreft
- Stap 10: Kijk op de multimeter of de stroom uit de linker voeding maximaal 0.1mA betreft.

Voltooid | Wanneer de spanning maximaal 500ms onder de 4V zakt en de stroom uit de linker kant van de voeding minder dan 0.1mA is wanneer de rechter voeding aan staat is de test geslaagd.

Figuur 24

### 4.2.2 Testresultaat voeding

Wanneer beide voedingen aangezet waren was het volgende beeld te zien:

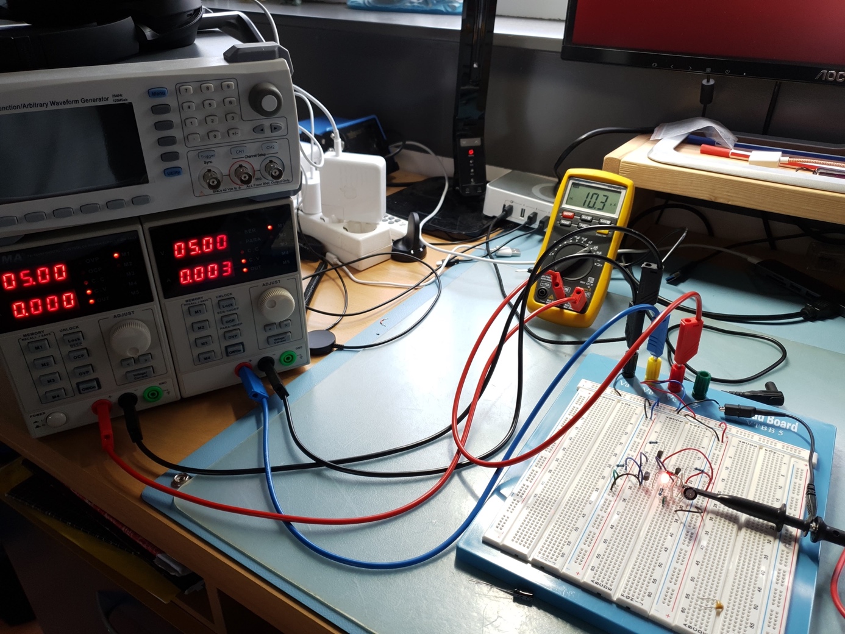
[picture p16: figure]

Figuur 25

Figuur 25 laat de testopstelling zien. De linker kant van de labvoeding simuleert de P1 stroombron en de rechterkant van de labvoeding simuleert de micro-USB stroombron. De multimeter geeft een stroom van 10.3uA aan. Dit is minder dan 0.1mA dus dit gedeelte van de test is geslaagd. Op de oscilloscoop aangesloten aan de uitgang van de schakeling waren de volgende beelden te zien:

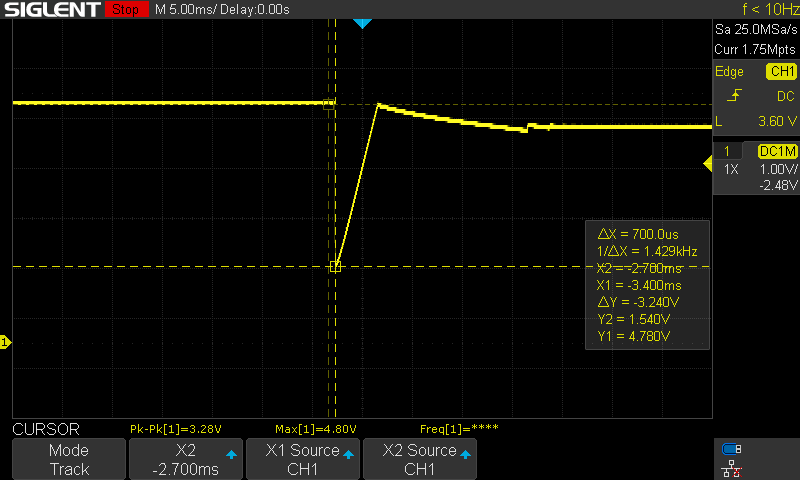
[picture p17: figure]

Figuur 26

Figuur 26 laat het gedrag zien nadat de micro-USB kant van de voeding aangezet werd. Door het schakelen van de Mosfets is een dip te zien in de uitgangsspanning. Links van de dip is de spanning uit de linker kant van de labvoeding te zien en rechts van de dip is de spanning uit de rechterkant van de labvoeding te zien. Ondanks dat zowel de linker- als de rechterkant van de labvoeding exact dezelfde instellingen hebben geven de voedingen een andere uitgangsspanning na de schakeling. Zolang deze spanningen boven de 3.4V blijven werkt de volledige schakeling prima. Wanneer de spanning alleen zover zou zakken zouden er relatief grote verliezen ontstaan, vandaar de eis dat de linkerkant boven de 4.5V en de rechterkant boven de 4.1V moet blijven. Y1 laat de spanning aan de linkerkant zien, dit is 4.78V.

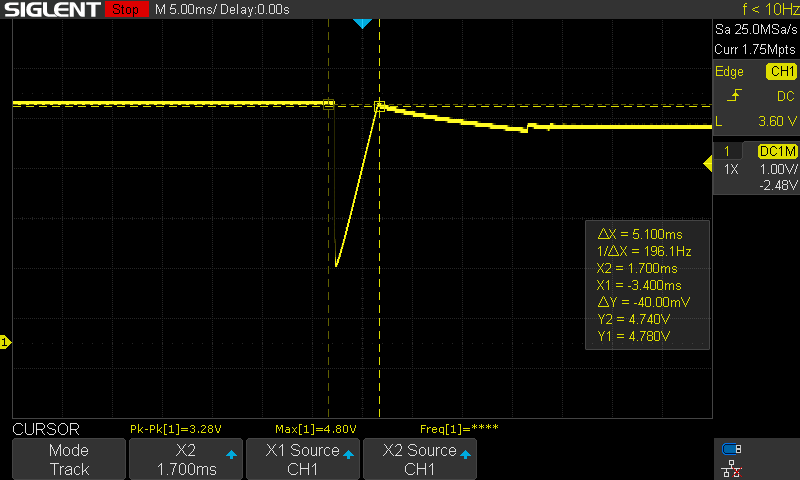
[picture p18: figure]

Figuur 27

Figuur 27 laat zien dat Y2 = 4.74V. Net na cursor Y2 zak de spanning weer iets in tot 4.5V. Dit is hoger dan 4.1V dus dit gedeelte van de test is ook geslaagd. Figuur 27 ook de duur van de dip zien door middel van ΔX, dit is 5.1ms. Dit valt ruim binnen de gestelde eis van 500ms dus ook dit laatste deel van de test is geslaagd.

## 4.3 Signaalomvormer

De signaalomvormer heeft een zoals in paragraaf 1.4 Omvormer beschreven minimale slew rate van 2.61V/(us) nodig om het signaal uit de P1 poort goed om te vormen.

### 4.3.1 Signaalomvormer test

Benodigdheden | - Functiegenerator - Oscilloscoop - Labvoeding

Stappen

- Stap 1: Stel de labvoeding in op 3.3V met een stroombegrenzing van 10mA.
- Stap 2: Stel de functiegenerator in op een PWM-signaal met een dutycycle van 80% en een piekspanning van 5V
- Stap 3: Zet de functiegenerator op HighZ.
- Stap 4: Sluit de labvoeding aan op de voedingspinnen van de unit.
- Stap 5: Sluit de functiegenerator aan op de signaalingang en GND van de unit.
- Stap 6: Sluit de oscilloscoop aan op de signaaluitgang en GND van de unit.
- Stap 6: Ze de labvoeding aan en kijk op de oscilloscoop of de uitgang van de unit 0V geeft.
- Stap 7: Zet de functiegenerator aan op een frequentie van 100kHz
- Stap 8: Zet de oscilloscoop aan
- Stap 9: Varieer de frequentie van de functiegenerator totdat het signaal op de oscilloscoop nog net aan vlakke bovenkanten heeft
- Stap 10: Meet met de cursors de duur van de rise time

Voltooid | De test wordt als geslaagd beschouwd wanneer er op de oscilloscoop te zien is dat de duur van de rise time maximaal 1.26us is met een maximale afwijking van 5%

Figuur 28

### 4.2.2 Testresultaat signaalomvormer

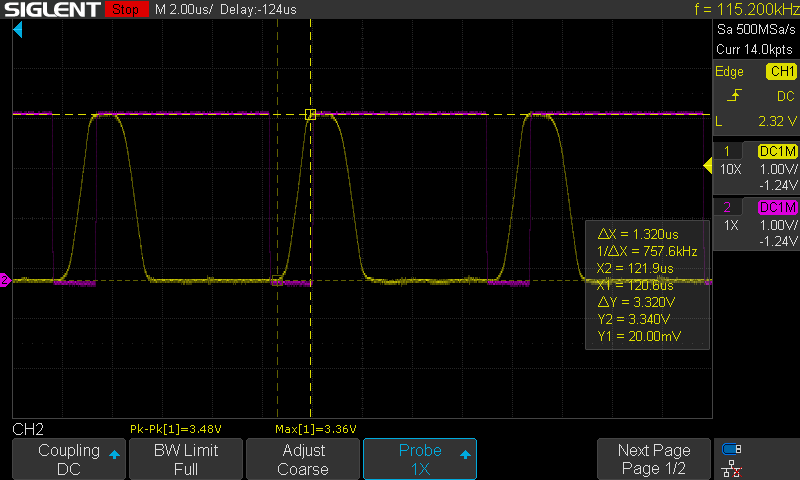
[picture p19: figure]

Figuur 29

Figuur 29 laat de minimaal acceptabele puls duur zien. Hier is te zien dat de rise time ∆X 1.32us is. Dit zit nog binnen de vereiste marge maar is niet perfect. Deze imperfecties worden veroorzaakt door de meetopstelling. Het spanningsverschil ∆Y is 3.32V, dit geeft een slew rate van (3.32V)/(1.32us)=2.5V/(us) . Deze opamp zou een slew rate van 4.5V/(us) moeten hebben. Dit is een erg groot verschil wat veroorzaakt wordt door de lange draden van de testopstelling. Deze gemeten slew rate is genoeg maar zal beter zijn wanneer de opamp op een PCB gesoldeerd is

## 4.4 Spanningsomvormer

Het is erg belangrijk om de spanningsomvormer afzonderlijk van de rest van het systeem te testen. Wanneer er een fout in deze unit zou zitten zou deze makkelijk de microcontroller kunnen beschadigen.

### 4.4.1 Spanningsomvormer test

Benodigdheden | - Labvoeding - Oscilloscoop
Stappen | - Stap 1: Sluit de oscilloscoop aan op de uitgang van de LDO - Stap 2: Zet de labvoeding op 5V met een stroombeperking van 100mA - Stap 3: Zet een weerstand van 56 ohm op de uitgang van de LDO - Stap 4: Zet de labvoeding aan - Stap 5: Kijk op de oscilloscoop of dat de uitgang van de LDO een continue waarde heeft van 3.3V
Voltooid | De test mag als geslaagd beschouwd worden wanneer er op de oscilloscoop een continue spanning van 3.3V te zien is met een maximale afwijking van 5 procent.

Figuur 30

### 4.4.2 Testresultaat spanningsomvormer

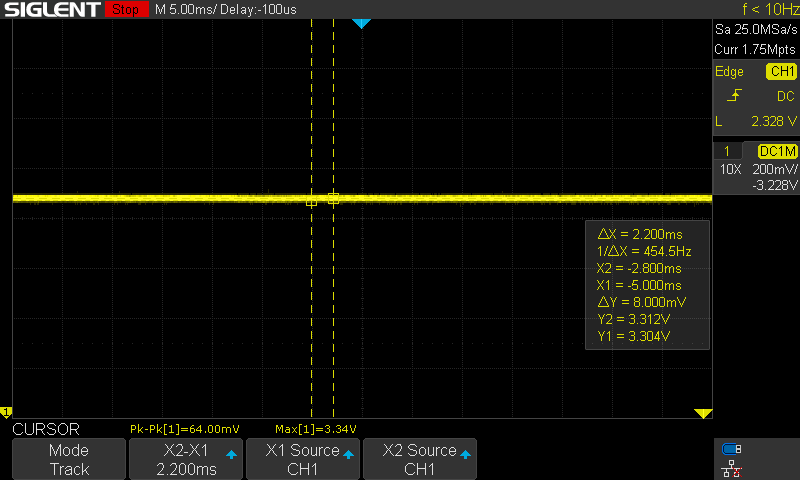
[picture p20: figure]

Figuur 31

Figuur 31 laat het oscilloscoopbeeld zien van de uitgang van de testopstelling. Hier is te zien dat een maximale spanning van 3.34V gemeten wordt, dat de cursor Y1 = 3.304V en dat de cursor Y2 = 3.312V aangeeft. Al deze waarden liggen ruim binnen de maximaal toelaatbare spanning van 4.465V dus deze test is geslaagd.

## 4.5 MCU-module

### 4.5.1 MCU-module test

Benodigdheden:

Stappen:

- Stap 1:

Wanneer er…

Benodigdheden | - Labvoeding
Stappen
Voltooid

Figuur 32

### 4.5.2 Testresultaat MCU-module

…

## 4.6 LED’s

### 4.6.1 LED’s test

Benodigdheden | - Functiegenerator - Zelfontworpen opamp testcircuit - Multimeter - Dubbele labvoeding - Oscilloscoop

Stappen

- Stap 1: Stel de linkerkant van de labvoeding in op 3.3V met een stroombeperking van 100mA en de rechterkant op 5V met een stroombeperking van 20mA
- Stap 2: Koppel de linkerkant van de labvoeding aan op de ingangen van het zelfontworpen opamp testcircuit
- Stap 3: Koppel de rechterkant labvoeding aan op het circuit van de LED’s
- Stap 4: Zet de functiegenerator op een blokgolf van 1Hz met een duty cycle van 50%
- Stap 5: Sluit de uitgang van de functiegenerator aan op de ingang van het zelfontworpen testcircuit
- Stap 6: Sluit de uitgang van het zelfontworpen opamp circuit aan op de ingang van één van de LED’s
- Stap 7: Sluit de oscilloscoop aan over de weerstand aan de gate van de Mosfet van de aangesloten LED
- Stap 8: Zet beide kanten van de labvoeding aan
- Stap 9: Kijk of dat de aangesloten LED niet gaat branden
- Stap 10: Zet de functiegenerator aan
- Stap 11: Kijk of dat de LED langzaam aan het knipperen is
- Stap 12: Kijk ook op de oscilloscoop of dat de stroom door de weerstand gelijk is aan 2.5mA met een afwijking van maximaal 20%
- Stap 13:

Voltooid

Figuur 33

### 4.6.2 Testresultaat LED’s

# 5. Integratietest

Bij de integratietest worden verschillende units samengevoegd. Hierbij wordt er getest of de individuele units ook bij elkaar werken zoals ze dat zouden moeten doen. Deze integratietest wordt op een ontworpen PCB uitgevoerd en niet op een breadboard. Een breadboard geeft te veel onzekerheid in de gemeten resultaten.

## 5.1 Unit voeding en unit omvormer

In deze test zullen de units voeding en omvormer bij elkaar gevoegd worden.

### 5.1.1 Test units voeding en spanningsomvormer

Benodigdheden | - Dubbele labvoeding - Oscilloscoop
Stappen | - Stap 1: Soldeer alle componenten op de PCB. - Stap 2: Stel beide kanten van de labvoeding in op een spanning van 5V met een stroombegrenzing van 20mA. - De linker kant van de labvoeding stelt de voeding vanuit de P1 poort voor, sluit deze kant van de voeding aan op de voedingsdraden van de RJ12 kabel. - De rechter kant van de labvoeding stelt de voeding vanuit de micro-USB poort voor, sluit deze kant van de voeding aan op de voedingsdraden van de micro-USB kabel. - Steek beide kabels in de desbetreffende poorten op de te testen PCB.
Voltooid

Figuur 34

# 6. PCB-ontwerp

Een eis voor het ontwerpen van de PCB was dat het ontwerp zo klein mogelijk gemaakt dient te worden zonder dat er op functionaliteit beperkt wordt. Zo klein mogelijk en zonder op functionaliteit te beperken is niet erg concreet maar het vinden van een balans is hier belangrijk. Zo is bijvoorbeeld het gebruiken van een module voor de NRF52832 niet erg efficiënt als het gaat om het zo klein mogelijk maken van het ontwerp maar het heeft genoeg voordelen om de voordelen van een losse NRF te overschaduwen. De uiteindelijke PCB te zien in Figuur 35 en is 2.54 cm breed en 5.92cm hoog.

Met dit ontwerp is een goede balans bereikt tussen afmetingen en functionaliteit. Zo zou het voor het Bluetooth bereik nog beter geweest zijn om de lege antenne kant van de module volledig uit te laten steken. Nu is ervoor gekozen om een uitsnede te maken in de PCB en geen power planes er direct naast te laten lopen, hierdoor komen de Bluetooth prestaties hoogstwaarschijnlijk erg in de buurt van een uit te laten steken module zonder dat het zoveel ruimte inneemt.

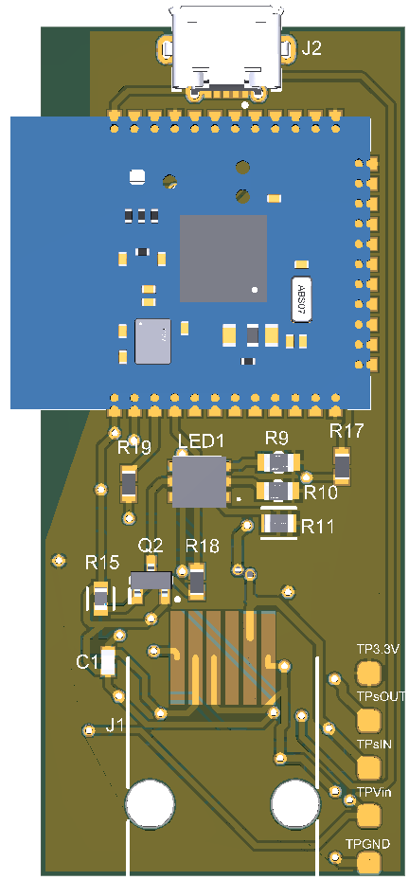
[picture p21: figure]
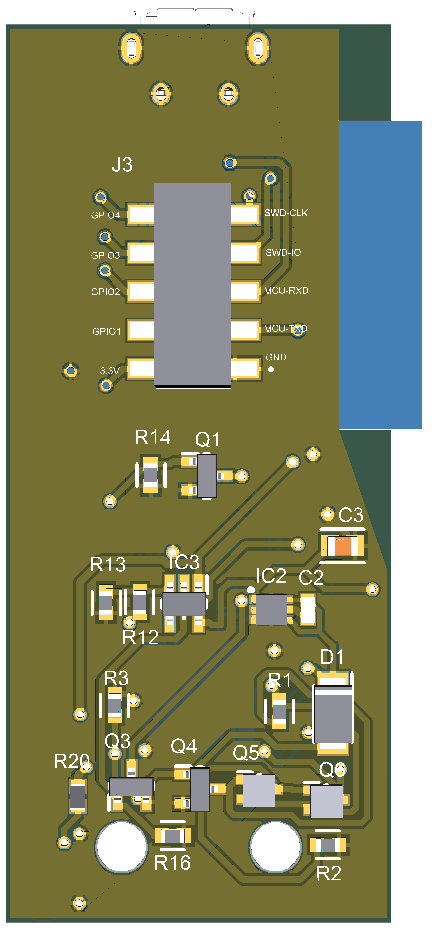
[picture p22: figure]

Figuur 35

Verder is ervoor gekozen om de testpunten links onderin te plaatsen, hierdoor is het mogelijk om de GND van een probe aan het GND punt vast te klemmen en met de punt van de probe de andere testpunten af te gaan. Naast de testpunten en in de twee grote gaten onderin zal de RJ12 connector geplaatst worden. Volledig aan de bovenkant is de micro-USB poort te zien. Door deze tegenover elkaar te plaatsen kan de PCB aan de RJ12 connector in de P1 poort hangen en wanneer nodig van stroom worden voorzien via de micro-USB poort. Doordat deze twee connectoren tegenover elkaar geplaatst zijn blijven de stressen op de connectoren en kabels minimaal wanneer deze aangesloten zijn. Daarnaast is er zoals goed te zien is in Figuur 35 gekozen om componenten aan beide kanten van de PCB te plaatsen. Dit maakt het assembleren wel een stuk ingewikkelder maar bespaart enorm veel ruimte. Verder is aan de onderkant de J3 connector te zien. Dit is de 2x5 2.54mm smd footprint voor het debuggen van de microcontroller en het mogelijk toevoegen van functies door vier beschikbare GPIO pinnen.

https://www.ti.com/sitesearch/docs/universalsearch.tsp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

Mogelijk geschikte schakelende voeding ic.

http://mouser.componentsearchengine.com/pcb-libraries.php

DC/DC converter component

https://devzone.nordicsemi.com/f/nordic-q-a/53691/re-changing-the-uart-tx-rx-pins

Veranderen van de UART pinnen

MDBT42Q-512KV2

Wordt gebruikt als module met NRF52832 erop.

http://domoticx.com/p1-poort-slimme-meter-hardware/

Website met heel veel informatie over verschillende DSMR-standaarden en de p1 poort zelf.

https://opencircuit.nl/Blog/Slimme-meter-uitlezer

Voorbeeld slimme meter uitlezen

https://nl.mouser.com/ProductDetail/Texas-Instruments/TPS7A2533DRVR?qs=OTrKUuiFdkbvIrFjA0rssQ%3D%3D

Gebruikte LDO

https://www.ti.com/lit/ds/symlink/lm3671.pdf?ts=1631871038849&ref_url=https%253A%252F%252Fwww.google.com%252F

Schakelende voeding gebruikt in HomeWizzard P1 meter

http://ncepower.com/Upload/NCE60P02Ydatasheet-10382020261.pdf

P-channel mosfet gebruik in Homewizzard

https://www.nordicsemi.com/Nordic-Partners/3rd-party-modules

Modules met Nordic chips

https://aconno.de/products/acn52832/

NRF52832 module uit Duitsland met ingebouwde RGB led

https://nl.mouser.com/ProductDetail/Toshiba/SSM6P36TULF?qs=B6kkDfuK7%2FCXuFvKzbJMTQ%3D%3D

Dual p-channel mosfet ic

https://nl.mouser.com/ProductDetail/Nexperia/PMEG4005AESFYL?qs=Yna0arPQ0CT21It55ddDRA%3D%3D

Schottky diode low dropout voltage

https://nl.mouser.com/ProductDetail/Nexperia/PMEG3020EP115?qs=GcY6OjH1zdnlY%252B06tUqEyw%3D%3D

Een iets grotere Schottky diode

https://nl.mouser.com/ProductDetail/ROHM-Semiconductor/SML-E12P8WT86?qs=4kLU8WoGk0vBFbk40ZI0Fw%3D%3D

Goedkope groene led

https://nl.mouser.com/ProductDetail/Wurth-Elektronik/615006138421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

Female RJ12 connector

https://nl.mouser.com/ProductDetail/Molex/95501-6669?qs=KUIzHt%2Fe91nGEpACmwALwA%3D%3D

Female RJ12 connector gebruikt in het ontwerp

https://nl.mouser.com/ProductDetail/Texas-Instruments/TLV9101IDBVR?qs=P1JMDcb91o6ZLUyc%2FHtrGA%3D%3D

In het ontwerp gebruikte opamp als signaalomvormer

https://nl.mouser.com/ProductDetail/Toshiba/SSM6P36TULF?qs=B6kkDfuK7%2FCXuFvKzbJMTQ%3D%3D

Dual p-channel mosfet

https://nl.mouser.com/ProductDetail/Nexperia/NX7002AKAR?qs=rkhjVJ6%2F3EJRNheJHlWytQ%3D%3D

Single n-channel mosfet

https://nl.mouser.com/ProductDetail/Toshiba/SSM6N7002KFULF?qs=lhkzy8lC%252BStoJHMOsaa2bw%3D%3D

Dual n-channel mosfet

https://nl.mouser.com/ProductDetail/Wurth-Elektronik/150060VS55040?qs=8Aa6%252B7C6HEumg%252B0cJZzvA%3D%3D

Groene LED

https://nl.mouser.com/ProductDetail/Wurth-Elektronik/150060BS55040?qs=fAHHVMwC%252BbiEgEQkEQqtiA%3D%3D

Blauwe LED

https://nl.mouser.com/ProductDetail/Lumileds/L1MC-RGB0035000MP0?qs=l4Gc20tDgJJ2Q8oG8kKRKQ%3D%3D

RGB led

https://nl.mouser.com/ProductDetail/Molex/47589-0001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

In het ontwerp gebruikte micro-USB poort

https://nl.mouser.com/ProductDetail/Nexperia/NX3020NAK215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

Single n-channel Mosfet op voorraad

https://nl.mouser.com/ProductDetail/Nexperia/NX3008PBKW115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

Single p-channel Mosfet op voorraad

Informatie

https://www.nktechnologies.com/engineering-resources/current-sensing-theory/

Verschillende manieren van stroom meten

https://en.wikipedia.org/wiki/Current_sensing

Current sensing

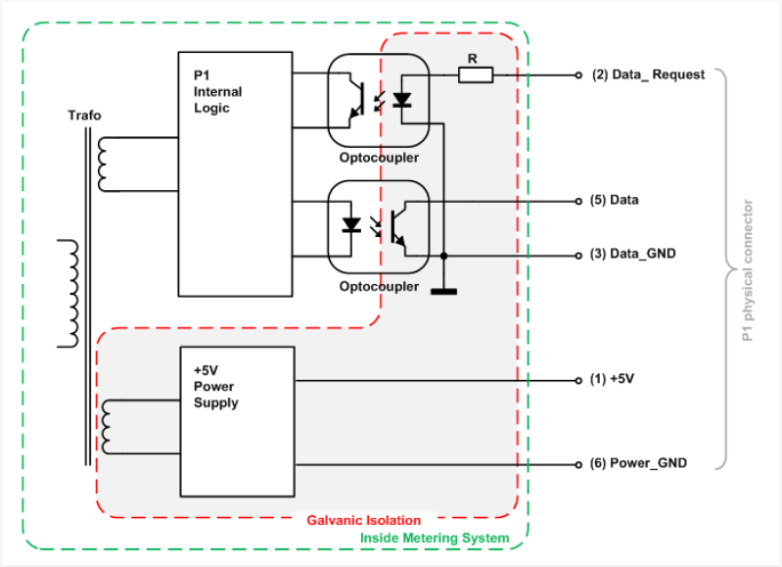
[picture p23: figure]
P1 poort slimme meter (hardware)

Figuur 36

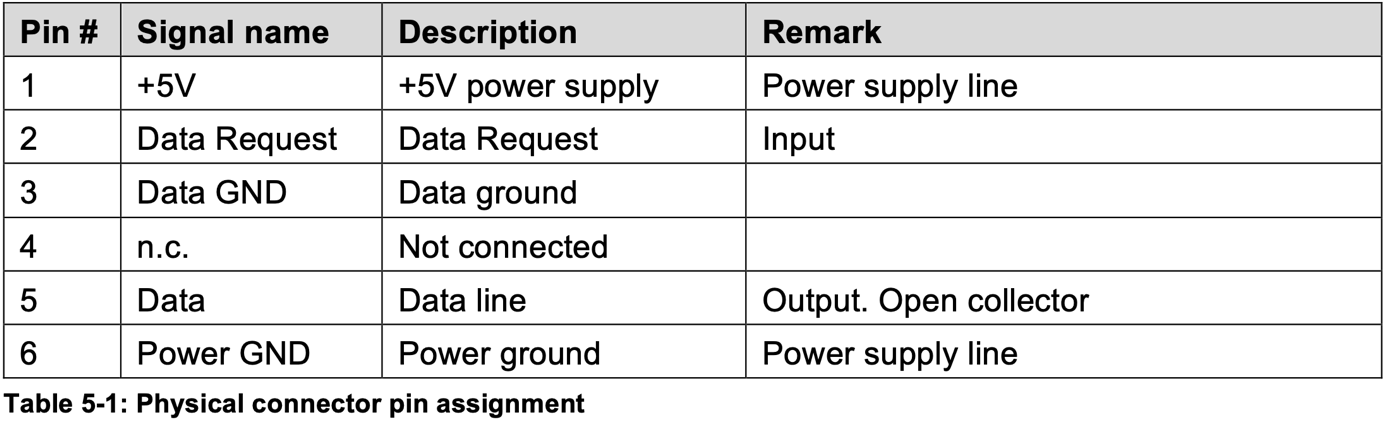
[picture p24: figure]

Figuur 37

# Bibliografie

[1] | N. Nederland, „DSMR 5.0 datasheet,” 26 2 2016. [Online]. Available: https://www.netbeheernederland.nl/_upload/Files/Slimme_meter_15_a727fce1f1.pdf.
[2] | N. Nederland, „DSMR 4.2 datasheet,” 26 6 2016. [Online]. Available: https://www.netbeheernederland.nl/_upload/Files/Slimme_meter_15_32ffe3cc38.pdf. [Geopend 23 9 2021].
[3] | Mouser, „Molex 95501-6669,” [Online]. Available: https://nl.mouser.com/ProductDetail/Molex/95501-6669?qs=KUIzHt%2Fe91nGEpACmwALwA%3D%3D. [Geopend 10 2021].
[4] | Mouser, „Wurth Elektronik 615006138421,” [Online]. Available: https://nl.mouser.com/ProductDetail/Wurth-Elektronik/615006138421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. [Geopend 10 2021].
[5] | Mouser, „Texas Instruments TLV9101IDBVR,” [Online]. Available: https://nl.mouser.com/ProductDetail/Texas-Instruments/TLV9101IDBVR?qs=P1JMDcb91o6ZLUyc%2FHtrGA%3D%3D. [Geopend 10 2021].
[6] | Mouser, „Texas Instruments TPS7A2533DRVR,” [Online]. Available: https://nl.mouser.com/ProductDetail/Texas-Instruments/TPS7A2533DRVR?qs=OTrKUuiFdkbvIrFjA0rssQ%3D%3D. [Geopend 10 2021].
[7] | Mouser, „STMicroelectronics LDFM33PVR,” [Online]. Available: https://nl.mouser.com/ProductDetail/STMicroelectronics/LDFM33PVR?qs=qzCNEk%252BRr%252Bbt5RX7rWJkeQ%3D%3D. [Geopend 10 2021].
[8] | Mouser, „Microchip Technology MCP1755S-3302E/MC,” [Online]. Available: https://nl.mouser.com/ProductDetail/Microchip/MCP1755S-3302E-MC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. [Geopend 10 2021].
[9] | Raytac, „MDBT42Q-512KV2,” [Online]. Available: https://www.raytac.com/product/ins.php?index_id=31. [Geopend 10 2021].
[10] | Aconno, „ACN52832,” [Online]. Available: https://aconno.de/products/acn52832/. [Geopend 10 2021].
[11] | Nordic Semi, „3rd party modules/modems,” [Online]. Available: https://www.nordicsemi.com/Nordic-Partners/3rd-party-modules. [Geopend 14 9 2021].
[12] | DomoticX, „P1 poort slimme meter (hardware),” [Online]. Available: http://domoticx.com/p1-poort-slimme-meter-hardware/. [Geopend 1 9 2021].

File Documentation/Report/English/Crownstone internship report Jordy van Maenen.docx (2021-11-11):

Internship report Jordy van Maenen

# Assignment 1: Smart Meter

# 1. Research

## 1.1 General:

Crownstone's first assignment is to design a product that can be connected (and powered) using the P1 port of a smart meter. A plug of the RJ11 6P4C or 6P6C type can be inserted into the P1 port of a smart meter. Pin 1 of this port has +5V and pin 6 is the power_GND pin. The power supply can supply a current of up to 250mA continuously when the smart meter is based on DSMR (Dutch Smart Meter Requirements) 5 or higher [1]. When the smart meter is based on DSMR 4 or older, a maximum of 100mA can be used continuously [2]. With DSMR 2, no power from the P1 port can be used at all. Exact numbers are not available but DSMR 5 seems to be the most commonly used standard at the moment followed by DSMR 4 and DSMR 2. DSMR 5 and 4 are very similar in that they use the same baud rate, a start bit, 8 data bits, no parity bit and a stop bit. However, there are a number of differences when it comes to the frequency with which the different standards send their information. DSMR 5 only sends all data every second and then sends measurements of gas consumption, thermal consumption and water consumption for the last 5 minutes. DSMR 4 sends all data every 10 minutes and then sends the last hour measurement of gas consumption, thermal consumption and water consumption. DSMR 2 transmits all data every hour. The smart meter uses an open collector output to send the data. This means that the output is either floating or connected to GND. To make a good signal, a pull-up resistor is needed.

## 1.2 Connector:

To use this port, a plug of the RJ11 6P4C or 6P6C type must be inserted. For this project the RJ11 6P6C connector (also called the RJ12 connector) is chosen. This connector has 2 pins more than the standard RJ11 connector, these pins enable using the power from the P1 port.


Figure 1

Figure 1 shows the pinout of the RJ12 connector, this table can be found in the datasheets of DSMR 4 [2] and 5 [1] on page 6. A maximum of 5mA may run into the data pin. The supply voltage from the P1 port may be a maximum of 5.5V, to realize a maximum current of 5mA a resistance value of at least 5.5/5mA = 1100Ω is required. The data line probably does not need to be able to supply 5mA for the rest of the circuit to function, therefor it is useful to use an higher pull-up resistor to reduce losses. To start the data transfer, a voltage between 4V and 5.5V must be applied to the request pin.

## 1.3 Inverter

The signal from the data pin is an inverted, too high, but otherwise a UART signal readable by a microcontroller. In this case, a high voltage (>1V, max 15V) is a 0 and a low voltage (<1V) is a 1. To make this signal readable for the microcontroller, it must be inverted and reduced to a maximum of 3.3V.

## 1.4 Signal P1 port

For the design and selection of a suitable converter, it is also useful to know the maximum switching speed of the signal from the P1 port. This can be investigated with a simple circuit consisting of a male RJ12 connector, a 6-core flat cable, a pull-up resistor and a prototype board.


Figure 2

Figure 2 shows the designed test board. The top stripped wire and the stripped wire on the right side must be connected to each other start the data transfer from the P1 port. The yellow center stripped wire is the measurement point for data pin 5. The black center stripped wire is the GND point. This test board can be plugged directly into the P1 port of a smart meter. In this test, it was inserted into a DSMR 5.0 meter to investigate the minimum pulse duration. Then the probe of the oscilloscope is connected to the yellow wire and the GND point to the black wire. The oscilloscope is turned on and the two completely stripped wires are connected to each other. This made the signal from the P1 port clearly visible on the oscilloscope.


Figure 3

Figure 3 shows the signal measured from the half stripped yellow wire, this is the signal from the P1 port. This measurement will be useful in the design phase.

## 1.5 power supply

The supply voltage from the P1 port can be a maximum of 5.5V and a minimum of 4V, generally this voltage is 5V. With the test board in Figure 2 it is also possible to measure the exact supply voltage of the tested smart meter.


Figure 4

Figure 4 shows this measurement. The maximum measured voltage can be seen at the bottom, this is 5.4V. This is probably a very short peak due to an outside disturbance. Y2 and Y1 can be read in the cursor box on the right of the image. These are the measured voltages on the cursors, both are 5.1V. This measurement shows that the actual voltage is very close to the expected 5V.

## 1.6 MCU

There are two options for the microcontroller unit, a ready-made module or a custom designed circuit with a separate NRF52832 chip. A ready-made module has the advantage that it is easy to implement, already approved and easy to update when a better module becomes available. The advantage of a self-designed circuit is that it can be made smaller than a ready-made module and that it can be fully adapted to the requirements of the product. In addition, the component costs are lower than for a ready-made module, but the design costs are higher. Whichever of the two options is chosen, several things must be considered during the design. For example, the design requires a 32MHz oscillator and 32KHz oscillator. These are both used for timing in the current Crownstone product, it is therefore convenient to use them in this design as well. Furthermore, decoupling capacitors should also be considered. These ensure that the supply voltage is equalized so that the microcontroller does not skip instructions or behave in any other unexpected way.

## 1.7 Software

Good software is also needed to process the information. Ideally, the product should be able to work with all smart meters in use. This would make the product more attractive to potential customers because there is no need to consider whether the device is suitable for the used smart meter. This does create some difficulties. As described earlier, the different standards are different from each other. With a DSMR 2 smart meter it is not possible to power external devices through the P1 port. Because of this a solution must be found to power the product with an external power supply, otherwise DSMR 2 meters won’t be supported by the product. In addition, it must be made possible in software to change the serial settings automatically while the program is running. This would make it possible to read the information from DSMR 2 meters. Furthermore, the program must also be able to recognize reference numbers. These reference numbers indicate what the data that come after means. All these reference numbers can be found in the DMSR 4 datasheet [2] and DSMR 5 datasheet [1]. The reference numbers given in the datasheet are all reference numbers, not every smart meter uses them all. Because of this, the program should also be able to skip numbers when they are not given. For example, a single-phase smart meter will not provide information about phases other than the one it is connected to.

# 2. Choices

To get this product working, several subsystems are needed. A connector, an inverter, a power supply and an MCU module. In addition, other choices have to be made that influence the functioning of the product.

## 2.1 Connector

The product must be able to be connected to a smart meter, this is done with an RJ12 (RJ11 6p6c) connector. One option is to provide the product with an RJ12 port so that a male RJ12 to male RJ12 cable can be used. Another option is to solder a cable with a male RJ12 plug on one side to the product on the other side. This would make that the product a lot flatter. This option has the disadvantage of higher production costs and that if the cable breaks, the entire product no longer works.

Solution | Advantages | Disadvantages
Solder RJ12 port on PCB | Inexpensive, prevents the product from becoming unusable | Makes the design a lot bigger
Solder RJ12 cable on PCB | Small design | Expensive, difficult assembly

Figure 5

Conclusion:

In this design the RJ12 port on the PCB will be used. Despite the large connector, the design will remain small.

## 2.2 Converter

Een omvormer is nodig om ervoor te zorgen dat het te hoge en geïnverteerde UART-signaal leesbaar te maken voor de microcontroller. Hiervoor zijn verschillende opties mogelijk. Er kan gebruik gemaakt worden van een opamp. Hierbij zal 3.3 volt op de positieve voeding gezet worden en de negatieve kant van de voeding aan GND aangesloten worden. Op de positieve ingang zal 1.65V volt gezet worden en op de negatieve ingang zal het signaal vanuit de P1 poort gezet worden. De 1.65V zal behaald worden door gebruik te maken van twee weerstanden van 1MΩ en deze als spanningsdeler te laten fungeren. Hierdoor zal de uitgang van de opamp laag zijn wanneer het signaal uit de P1 poort hoger is dan 1.65 volt en 3.3 volt zijn wanneer het signaal uit de P1 poort lager is dan 1.65 volt.

Een andere optie is het gebruiken van een transistorschakeling. Hiermee zou de schakeling uit alleen transistoren en weerstanden bestaan. Dit heeft als voordeel dat het goedkoper in onderdelen is. Nadelen zijn alleen dat er actief een stroom in moet gaan lopen om een spanning te krijgen. In het ideale geval zou dit bij een opamp niet het geval zijn.

Oplossing | Voordelen | Nadelen
Opamp | Het is één component dat zowel de spanning verlaagt als inverteert. Makkelijk te fabriceren. Blijft snel schakelen 3.3V onder een load. | Duurder
Transistor en weerstanden | Goedkoop | Output komt niet bij GND. Gevoeliger voor temperatuur. Meer componenten dus meer solderen.

Figuur 6

Conclusie:

Er is gekozen om in het ontwerp gebruik te maken van een opamp. Hier is gemak en accuraatheid belangrijker.

## 2.3 Voeding

Een voeding zorgt ervoor dat de spanning die het product in gaat geschikt is om gebruikt te worden door de individuele componenten. Hiervoor zijn er meerdere opties beschikbaar, een LDO of een schakelende voeding. Een LDO heeft als voordeel dat het erg eenvoudig te implementeren is, zeker wanneer er gekozen wordt voor een LDO met een gefixeerde uitgangsspanning. Het nadeel van een LDO is dat er meer vermogen verspild wordt in de vorm van warmte dan bij een schakelende voeding. Een schakelende voeding heeft als voordeel dat hij erg zuinig is. Nadelen van een schakelende voeding zijn dat hij meer ruis veroorzaakt, lastiger te implementeren is en duurder is.

Oplossing | Voordelen | Nadelen
LDO | Makkelijk en goedkoop | Minder efficiënt
Schakelende voeding | Energiezuinig | Duurder, meer componenten, meer ruis.

Figuur 7

Conclusie:

Er is gekozen om in het ontwerp gebruik te maken van de LDO. Deze zijn wel minder efficiënt alleen het stroomverbruik van het gehele ontwerp zal minimaal zijn dus ook de verspilling.

## 2.4 MCU-module

De MCU-module is nodig om alle binnenkomende informatie te verwerken en daarop te reageren. Deze module moet programmeerbaar zijn zodat er eigen software op gezet kan worden. Als microcontroller wordt de NRF52832 gebruikt. Er zijn alleen verschillende manieren om deze microcontroller te implementeren, dit kan in de vorm van een kant en klare module of een zelfontworpen module. Het voordeel van een kant en klare module is dat deze makkelijk te implementeren zijn en makkelijk te vervangen zijn wanneer er van een andere microcontroller gebruikgemaakt wil worden. Het voordeel van een zelfontworpen module is dat de kosten van de componenten lager zijn en dat de schakeling op een eigen PCB erg klein gemaakt kan worden.

Oplossing | Voordelen | Nadelen
Kant en klare module | Makkelijk te implementeren, makkelijk te upgraden. | Prijs van de component ligt hoger dan de losse componenten van een zelfontworpen module.
Zelfontworpen module | Kan erg klein gemaakt worden, goedkoper in de ontwikkeling. | Het ontwerpen is lastig, tijdrovend en daardoor duur. Wanneer een nieuwe microcontroller uit komt moet de gehele pcb herontworpen worden.

Figuur 8

Conclusie:

Er is gekozen om in het ontwerp gebruik te maken van een kant en klare module. De aanschaf kosten worden uiteindelijk overschaduwd door de ontwerpkosten van een zelfontworpen module.

## 2.5 Wel of geen externe voeding nodig

Volgens de als eerst opgestelde eisen moet het te ontwerpen product in ieder geval gevoed kunnen worden vanuit de P1 poort. Na verder onderzoek is er alleen ontdekt dat oudere slimme meters niet de mogelijkheid hebben om externe apparatuur via de P1 poort te voeden. Deze oudere slimme meters worden in ieder geval niet meer geplaatst maar zijn nog wel in gebruik. Exacte hoeveelheden zijn ook via de energieleveranciers lastig te krijgen. Wanneer er in het ontwerp geen mogelijkheid meegenomen wordt om het product via bijvoorbeeld een micro USB-poort te voeden zullen de oudere slimme meters van DSMR-versie 2 of lager niet ondersteund worden.

Oplossing | Voordelen | Nadelen
Geen externe voedingsmogelijkheid | Makkelijker te ontwerpen, goedkoper in productie, makkelijker in code te implementeren | Het product zal niet op oudere slimme meters werken, werkt dan op minder slimme meters dan de concurrentie
Wel een externe voedingsmogelijkheid | De consument hoeft niet na te denken wat voor slimme meter er geïnstalleerd is | Hogere implementatiekosten, hogere productiekosten

Figuur 9

Conclusie:

Er is gekozen om in het ontwerp wel de mogelijkheid om het product extern te voeden toe te voegen. Hierdoor hoeft de consument niet na te denken of dit product wel in zijn of haar specifieke situatie werkt. Wanneer dit niet mogelijk zou zijn zou er een extra reden zijn om voor een concurrerend product te kiezen.

## 2.6 LED’s

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

Oplossing | Voordelen | Nadelen
Losse LED’s direct op signaallijnen | Makkelijker te ontwerpen, goedkoper in productie, minimale hoeveelheid code nodig | De LED’s hebben maar één functie en die kan later ook niet aangepast worden
RGB LED met microcontroller aansturen | Softwarematig de functies aanpassen van de LED’s | Meer componenten nodig

Figuur 10

Conclusie:

Er is gekozen om een RGB-led met behulp van Mosfets op de microcontroller aan te sluiten. Het is iets duurder maar brengt wel veel meer mogelijkheden met zich mee.

# 3. Design

## 3.1 Component selection

- For the female RJ12 connector, the Molex 95501-6669 connector has been chosen. This connector is available from stock and is largely SMD. This allows more components to be placed at the bottom if necessary.
- Voor de als omvormer gebruikte opamp is er gekozen voor de TLV9101IDBVR van TI. Dit is een low power rail-to-rail opamp, hierdoor is de output zo dicht mogelijk bij 3.3V of GND waardoor een erg duidelijk signaal ontstaat.
- Voor de voeding is er gekozen voor een TPS7A2533DRVR van TI. Deze LDO heeft een Ultra-low quiescent current van 2 μA en een maximum dropout voltage van minder dan 340 mV bij 300 mA waardoor het een erg zuinige LDO is. Deze LDO geeft ook standaard 3.3V zonder dat daarvoor externe weerstanden nodig zijn wat ruimte scheelt op de PCB en waardoor de spanning niet kan veranderen door in temperatuur veranderende weerstanden.
- Voor de MCU-module is er gekozen voor een ACN52832 van Oconno. Deze module is goed voorradig, en is makkelijk te implementeren. Alle pinnen zitten aan de buitenkant wat het solderen en debuggen een stuk makkelijker maakt. Deze module is ook te vinden op de website van Nordic Semi [3].
- Als connector voor een externe voeding is er gekozen voor een micro-USB poort. Deze poort is wel al behoorlijk op leeftijd alleen ze zijn goedkoop om te implementeren en zijn er al veel geschikte kabels en adapters op de markt. USB geeft standaard ook een spanning van +5V, dit is dezelfde spanning als uit de P1 poort. Dit versimpelt het ontwerp ook ten opzichte van wanneer er een andere poort gekozen zou zijn.
- Er is gekozen om een 2x5 2.54mm smd footprint te gebruiken voor het debuggen. Deze connector wordt op dit moment ook op het hoofdproduct van Crownstone gebruikt voor het debuggen en programmeren. Het gebruiken van dezelfde connector maakt het debuggen en programmeren van het te ontwerpen product voor het bedrijf een stuk makkelijker.
- Voor de RGB-led is er gekozen voor de L1MC-RGB0035000MP0 van Lumileds. Deze RGB-led is goed uit voorraad leverbaar, is meer dan fel genoeg en goedkoop.

## 3.2 Ontwerp units

Hieronder zal uitgelegd worden hoe de hierboven genoemde componenten geïmplementeerd zullen worden in de verschillende units en waarom ze op die manier geïmplementeerd worden.

### 3.2.1 RJ12 connector

Pin 3(data_gnd) zal aan pin 6(power_gnd) verbonden worden, het is niet nodig dat de data een afzonderlijke ground heeft. Pin 4 is NC dus blijft floating. Pin 5 is de data pin, deze pin is een open collector uitgang. Om uit deze uitgang een nuttig signaal te krijgen is een pull-up weerstand nodig. Volgens hoofdstuk 4.6 van de datasheet van DSMR 4.2 [2] en hoofdstuk 5.8 van DSMR 5,0 [1] mag er door het apparaat dat aan de P1 poort aangesloten zit maximaal 5mA geleverd kunnen worden aan de data pin. Zoals in hoofdstuk 1 benoemd is er minimaal een weerstand van 1100Ω nodig om deze maximale stroom te realiseren. Er is alleen gekozen voor een hogere weerstand van 10KΩ om de stroom te beperken tot 0.55mA en zo verspilling te verkleinen. Deze 10KΩ pull-up weerstand zal aan de pin 2(request) verbonden worden zodat de data uit pin 5 leesbaar is wanneer de data opgevraagd wordt.

Pin 1(+5V) en pin 2(request) zullen aan een later genoemde schakeling gekoppeld worden. Figuur 11 laat de hierboven uitgelegde informatie goed zien. J1 is hier de RJ12 connector. Zoals later in dit hoofdstuk ook gezien zal worden wordt er vaak gebruikgemaakt van 0603 weerstanden en condensatoren. Er is voor dit formaat gekozen omdat deze nog wel met de hand te solderen zijn en omdat er van dit formaat al veel weerstanden en condensatoren op voorraad zijn wat relatief veel verschil maakt in de inkoopkosten omdat deze vervolgens niet meer in kleine hoeveelheden besteld hoeven te worden.


Figuur 11

### 3.2.2 Voeding

De micro USB-poort heeft meerdere shield pinnen. Het wordt aangeraden om deze aan ground te verbinden, in dit ontwerp is dat niet noodzakelijk omdat er geen data vanuit de micro USB-poort gehaald zal worden maar het is alsnog nuttig omdat dit de connectie op de PCB verstevigt. Van deze poort zullen alleen de GND en VBUS-pin gebruikt worden om te dienen als externe voeding.

Omdat er gekozen is om het te ontwerpen product zowel via de P1 poort te kunnen voeden als via een externe voeding is er een schakeling nodig die tussen deze twee bronnen schakelt. De bedoeling is dat wanneer de externe voeding in het product gestoken wordt dat er stroom uit deze bron gebruikt wordt en niet vanuit de P1 poort onafhankelijk of dat de P1 poort de stroom kan leveren. Ook mag het niet mogelijk zijn dat er stroom één van de voeding in loopt, hierdoor kunnen de voedingen beschadigd raken.

Een optie zou zijn om beide voedingsbronnen met twee diodes aan elkaar te koppelen, hierdoor kan er geen stroom één van de voeding in lopen. Het nadeel is alleen dat met dit systeem vrijwel alle stroom gebruikt wordt van de voeding met de hoogste spanning. Dit is natuurlijk niet de bedoeling, wanneer een klant een externe voeding in het apparaat steekt moet deze voeding wel gebruikt worden.


Figuur 12

Een tweede optie is de in Figuur 12 weergegeven schakeling. Wanneer de externe voeding niet aangesloten zit is Nmosfet M3 laag getrokken, deze zorgt dat Pmosfet M1 hoog getrokken wordt waardoor deze niet in geleiding gaat en vervolgens Pmosfet M2 laag trekt waardoor deze wel in geleiding gaat en de voedingsspanning vanuit de P1 poort doorlaat. Wanneer de externe voeding wel aangesloten zit wordt dus M3 hoog getrokken waardoor deze in geleiding gaat, vervolgens M1 laag trekt en deze ook in geleiding gaat waardoor M2 hoog getrokken wordt en niet in geleiding gaat. Hierdoor heeft de externe voeding altijd voorrang. De externe voeding heeft alleen een spanningsval over diode D1, dit is alleen niet erg omdat de externe voeding minimaal 5 volt is en er in de rest van de schakeling alleen 3.3V gebruikt wordt. In dit schema simuleert R4 de load, deze weerstand zal dus niet aanwezig zijn in het uiteindelijke ontwerp. Voor de N-channel Mosfet wordt er gebruik gemaakt van de NX3020NAK,215, dit is een low power Mosfet. Voor de P-channel Mosfet wordt de NX3008PBKW,115,LF gebruikt. Van deze Mosfet zullen er twee gebruikt worden in de schakeling. De N-channel Mosfet heeft een Rds on van 4,5 Ohm en de P-channel Mosfet een Rds on van 4,1 ohm. Dit is in beide gevallen erg weinig waardoor de verspilling minimaal is.

De uitgang van de in Figuur 12 weergegeven schakeling zal vervolgens aan pin 2 van de RJ12 poort gekoppeld worden. Hierdoor staat er altijd een spanning die in ieder geval hoger is dan de minimaal benodigde 4 Volt op de request pin. Hierdoor zal de P1 poort altijd data gaat zenden wanneer het te ontwerpen product aangesloten is en een voeding heeft. De uitgang van de hierboven weergegeven schakeling zal ook op de ingang van de LDO aangesloten worden. Figuur 13 laat het in Figuur 12 weergegeven schema nog een keer zien met hierbij exact de te gebruiken componenten.


Figuur 13

### 3.2.3 Signaalomvormer

Voor de signaalomvormer wordt de opamp gebruikt als comparator, in Figuur 14 is de gebruikte schakeling te zien. De positieve kant van de voeding wordt aangesloten op de 3.3V van de uitgang van de LDO en de negatieve voedingskant wordt aangesloten op de GND. Op de positieve kant wordt via een spanningsdeler met twee keer een 1M ohm weerstand de 3.3V verlaagd naar 1.65V. Op de negatieve kant wordt het signaal vanuit de P1 meter aangesloten. De spanningsdeler is nodig om ervoor te zorgen dat de opamp niet twee signalen met elkaar hoeft te vergelijken die beiden minimaal gelijk zijn aan de voedingsspanning. Dit zou ervoor zorgen dat de output van de opamp onvoorspelbaar zou worden.


Figuur 14

Figuur 15 laat het te gebruiken schema nogmaals zien maar nu met de juiste componenten.


Figuur 15

### 3.2.4 Spanningsomvormer

Aan de LDO is een 1uF condensator op de ingang en een 2.2uF condensator op de uitgang geplaatst. Deze condensatorwaarden worden aangeraden door de datasheet, er wordt ook rekening gehouden met de gemiddelde degradatie en afwijking van de condensatoren. Deze LDO beschikt ook over een “power good” pin. Deze pin wordt in dit ontwerp niet gebruikt en de datasheet raadt dan aan om deze aan GND te koppelen voor een verbeterde warmte dissipatie. Ditzelfde geldt voor de NC pin, deze pin heeft helemaal geen functie maar ook hiervan wordt aangeraden om deze aan GND te koppelen. De enable pin wordt direct aan de ingang gekoppeld zodat de LDO altijd werkt wanneer er een spanning op de ingang staat.


Figuur 16

### 3.2.5 MCU

Aan de ACN52832 module zullen alle deelsystemen uiteindelijk gekoppeld worden. Voor het debuggen wordt er gebruik gemaakt van de 2x5 2.54mm smd footprint. De pinnen van deze footprint zijn op dezelfde manier aan de NRF52832 gekoppeld als dat nu gedaan is in het huidige Crownstone product. Hierdoor hoeft er in de code zo min mogelijk veranderd te worden voor het confituren van deze pinnen. Deze footprint heeft daarnaast ook als voordeel dat er male-headers op gezet kunnen worden. Dit maakt het programmeren en debuggen een stuk eenvoudiger.

Figuur 17 laat de MCU-unit en alle verbindingen daaraan goed zien.


Figuur 17

### 3.2.6 LED’s

Voor het schakelen van de gekozen RGB-led is er gekozen om gebruik te maken van de NX3020NAK,215 n-channel Mosfet. Deze Mosfet heeft een lage ingangscapaciteit van 20pF maximaal. Deze Mosfet is al eerder in een grote hoeveelheid besteld waarmee kosten van het klein inkopen bespaard blijven. Tussen de GPIO-pin van de microcontroller en de Mosfet is nog een weerstand van 4.7K ohm geplaatst. Deze weerstand zorgt ervoor dat de momentane stroom beperkt wordt en de microcontroller bij snel schakelen niet beschadigd raakt. De NRF52832 kan bij een voedingsspanning van 3.3V ongeveer 25mA afvoeren en nog minder dan dat voeden vanuit de GPIO pinnen (in theorie is de sink en source current gelijk alleen NRF heeft meer GND dat Vdd pinnen waardoor afgeraden wordt om 25mA te voeden vanuit de GPIO pinnen). Figuur 18 is afkomstig uit de datasheet van de NRF52832. De weergegeven stromen zijn alleen maximumwaarden dus het is niet verstandig om een PWM-signaal te generen die die stroom moet kunnen leveren. In Figuur 19 zijn 10 cycli van te zien van een PWM-signaal met een duty cycle van 50%. Met deze schakelsnelheid wordt een frequentie van 1/(0.2 × 10^(-3)) × 10 =50Khz gemakkelijk behaald, dit is meer dan voldoende.


Figuur 18


Figuur 19

In serie met de opamp en LED’s is ook nog een weerstand nodig om de stroom te beperken. Deze weerstand kan uitgerekend worden met de volgende formule:

Rs = (Vs-Vf)/(If)

Hier is Rs de benodigde weerstandswaarde, Vs is de voedingsspanning, Vf is de spanningsval over de LED en If is de maximale stroom door de LED.

De gekozen RGB LED heeft over de verschillende kleuren LED’s een andere spanningsval, de maximale stroom door elk van de LED’s is 20mA. De rode LED heeft een spanningsval van 2.1V, de groene LED van 2.8V en de blauwe LED van 3.0V. De rode LED heeft dus minimaal een weerstand nodig van:

Rsr= (3.3-2.1)/(20 × 10^(-3))=60Ω

De groene LED heeft minimaal een weerstand nodig van:

Rsg= (3.3-2.8)/(20 × 10^(-3))=25Ω

En de blauwe LED heeft minimaal een weerstand nodig van:

Rsb= (3.3-3.0)/(20 × 10^(-3))=15Ω

De RDSon van de Mosfet ligt tussen de 3Ω en 13Ω. Deze weerstand staat dus ook nog in serie met de LED. Voor het kiezen van de weerstandswaarde is het handig om uit te gaan van een lage RDSon zodat er alleen maar minder stroom kan lopen en niet meer. Er is voor gekozen om de stroom te beperken tot 15mA max, hierdoor zal de LED niet snel kapotgaan. Er is dan voor de rode LED een totale weerstand nodig van:

Rsr= (3.3-2.1)/(15 × 10^(-3))=80Ω

Voor de groene LED een weerstand van:

Rsg= (3.3-2.8)/(15 × 10^(-3))=33.3Ω

Voor de blauwe LED een weerstand van:

Rsb= (3.3-3.0)/(15 × 10^(-3))=20Ω

Van deze waarde wordt de minimale RDSon van de Mosfet afgehaald, Rsr = 80 – 3 = 77Ω,

Rsg = 33.3 – 3 = 30.3Ω en Rsb = 20 – 3 = 17Ω. De beschikbare weerstanden die hiervan in de buurt komen zijn: Rsr = 82Ω, Rsg = 33Ω en Rsb = 18Ω.

In dit ontwerp wordt driemaal de NX3020NAK,215 n-channel Mosfet gebruikt voor het schakelen van de LED’s.

Figuur 20 laat de hierboven uitgelegde schakeling zien met de connecties naar de MCU unit.


Figuur 20

### 3.2.7 Overig

Naast alle losse units zijn er ook nog andere delen ontworpen. Een ander ontwerp zijn de testpunten. Testpunten zijn erg belangrijk omdat hiermee makkelijk verschillende spanningen in de PCB getest kunnen worden terwijl de PCB al volledig gefabriceerd is. De blauwe cirkels met daarin P1 die te zien zijn in eerdere figuren stellen de gebruikte testpunten voor. Er is gekozen om een testpunt te zetten op de 3.3V, het ingangssignaal van de signaalomvormer, het uitgangssignaal van de spanningsomvormer, de ingangsspanning van de spanningsomvormer en GND.

# 4. Unittests

In dit hoofdstuk zullen de verschillende unittests beschreven worden en zullen wanneer uitgevoerd de testresultaten er direct onder gezet worden.

## 4.1 RJ12 connector

Deze test is makkelijk uit te voeren maar is wel belangrijk. Wanneer er intern een connectie verbroken is zou het wanneer geïntegreerd met de rest van het systeem erg lang duren voordat er ontdekt wordt dat de connector kapot is.

### 4.1.1 RJ12 connector test

Benodigdheden | - Multimeter
Stappen | - Stap 1: Zet de multimeter op de doorpiep functie. - Stap 2: Meet of dat elk van de pinnen aan de onderkant van de connector verbonden is met de pinnen aan de binnenkant van de connector.
Voltooid | Wanneer er bij de laatste stap geen problemen gevonden worden is de test met succes afgerond.

Figuur 21

### 4.1.2 Testresultaat RJ12 connector

Deze test is geslaagd, elke van de pinnen aan de binnenkant is verbonden aan de juiste pin aan de onderkant.

## 4.2 Voeding

Het is belangrijk dat de voeding eerst als individueel systeem getest wordt. Wanneer deze pas getest zou worden bij het integreren zouden er door een niet functionerende voeding andere systemen beschadigd kunnen raken.

### 4.2.1 Voeding test

Benodigdheden | - Dubbele labvoeding - Oscilloscoop - Multimeter

Stappen

- Stap 1: Zet beide kanten van de labvoeding op 5V met een stroomlimiet van 250mA
- Stap 2: Zet de multimeter op stroom meten
- Stap 3: Zet de multimeter in serie met de uitgang van de linker kant van de voeding
- Stap 4: Sluit de linker kant van de voeding met de multimeter in serie aan op de P1 ingang van de schakeling
- Stap 5: Sluit de rechter kant van de voeding aan op de micro-USB kant van de schakeling.
- Stap 6: Sluit de oscilloscoop aan op de uitgang van de schakeling
- Stap 7: Sluit een weerstand van 56 ohm aan op de uitgang, deze weerstand simuleert de load van de rest van het circuit
- Stap 8: Zet de linker kant van de voeding aan en kijk op de oscilloscoop of de spanning minimaal 4.5V betreft
- Stap 9: Zet de rechter kant van de voeding aan en kijk op de oscilloscoop of de spanning minimaal 4.1V betreft
- Stap 10: Kijk op de multimeter of de stroom uit de linker voeding maximaal 0.1mA betreft.

Voltooid | Wanneer de spanning maximaal 500ms onder de 4V zakt en de stroom uit de linker kant van de voeding minder dan 0.1mA is wanneer de rechter voeding aan staat is de test geslaagd.

Figuur 22

### 4.2.2 Testresultaat voeding

…

## 4.3 Signaalomvormer


Figuur 23

Figuur 23 laat de kleinste signaalduur zien die de P1 poort kan geven. Deze puls duurt ongeveer 7.6us. De omvormer moet minimaal de helft van deze duur aankunnen om nog genoeg marge te hebben en ervoor te zorgen dat er nog een duidelijk signaal ontstaat.

### 4.3.1 Signaalomvormer test

Benodigdheden | - Functiegenerator - Oscilloscoop - Labvoeding - DSMR 5.0 slimme meter

Stappen

- Stap 1: Stel de labvoeding in op 3.3V met een stroombegrenzing van 10mA.
- Stap 2: Stel de functiegenerator in op een PWM-signaal met een dutycycle van 80% en een piekspanning van 5V
- Stap 3: Zet de functiegenerator op HighZ.
- Stap 4: Sluit de labvoeding aan op de voedingspinnen van de unit.
- Stap 5: Sluit de functiegenerator aan op de signaalingang en GND van de unit.
- Stap 6: Sluit de oscilloscoop aan op de signaaluitgang en GND van de unit.
- Stap 6: Ze de labvoeding aan en kijk op de oscilloscoop of de uitgang van de unit 0V geeft.
- Stap 7: Zet de functiegenerator aan op een frequentie van 100kHz
- Stap 8: Zet de oscilloscoop aan
- Stap 9: Varieer de frequentie van de functiegenerator totdat het signaal op de oscilloscoop nog net aan vlakke bovenkanten heeft
- Stap 10: Meet met de cursors of de duur van die vlakke bovenkant minimaal 3.8ms is.

Voltooid | De test wordt als geslaagd beschouwd wanneer er op de oscilloscoop te zien is dat de duur van de vlakke bovenkant minimaal 3.8us

Figuur 24

### 4.2.2 Testresultaat signaalomvormer


Figuur 25

Figuur 25 laat de minimaal acceptabele puls duur zien. Hier is te zien dat deltaX 880ns is. Dit is ongeveer een vierde van wat benodigd is dus deze test is geslaagd.

## 4.4 Spanningsomvormer

Het is erg belangrijk om de spanningsomvormer afzonderlijk van de rest van het systeem te testen. Wanneer er een fout in deze unit zou zitten zou deze makkelijk de microcontroller kunnen beschadigen.

### 4.4.1 Spanningsomvormer test

Benodigdheden | - Labvoeding - Oscilloscoop
Stappen | - Stap 1: Sluit de oscilloscoop aan op de uitgang van de LDO - Stap 2: Zet de labvoeding op 5V met een stroombeperking van 100mA - Stap 3: Zet een weerstand van 56 ohm op de uitgang van de LDO - Stap 4: Zet de labvoeding aan - Stap 5: Kijk op de oscilloscoop of dat de uitgang van de LDO een continue waarde heeft van 3.3V
Voltooid | De test mag als geslaagd beschouwd worden wanneer er op de oscilloscoop een continue spanning van 3.3V te zien is met een maximale afwijking van 5 procent.

Figuur 26

### 4.4.2 Testresultaat spanningsomvormer

….

## 4.5 MCU-module

### 4.5.1 MCU-module test

Benodigdheden:

Stappen:

- Stap 1:

Wanneer er…

Benodigdheden | - Labvoeding
Stappen
Voltooid

Figuur 27

### 4.5.2 Testresultaat MCU-module

…

## 4.6 LED’s

### 4.6.1 LED’s test

Benodigdheden | - Functiegenerator - Zelfontworpen opamp testcircuit - Multimeter - Dubbele labvoeding - Oscilloscoop

Stappen

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

Voltooid

Figuur 28

### 4.6.2 Testresultaat LED’s

# 5. Integratietest

Bij de integratietest worden verschillende units samengevoegd. Hierbij wordt er getest of de individuele units ook bij elkaar werken zoals ze dat zouden moeten doen.

## 5.1 Unit voeding en unit omvormer

In deze test zullen de units voeding en omvormer bij elkaar gevoegd worden.

### 5.1.1 Test units voeding en omvormer

Benodigdheden | - Dubbele labvoeding - Oscilloscoop
Stappen | - Stap 1: Sluit de voeding aan op de ingang van de omvormer
Voltooid

Figuur 29

# 6. PCB-ontwerp

Een eis voor het ontwerpen van de PCB was dat het ontwerp zo klein mogelijk gemaakt dient te worden zonder dat er op functionaliteit beperkt wordt. Zo klein mogelijk en zonder op functionaliteit te beperken is niet erg concreet maar het vinden van een balans is hier belangrijk. Zo is bijvoorbeeld het gebruiken van een module voor de NRF52832 niet erg efficiënt als het gaat om het zo klein mogelijk maken van het ontwerp maar het heeft genoeg voordelen om de voordelen van een losse NRF te overschaduwen. De uiteindelijke PCB te zien in Figuur 30 en is 2.54 cm breed en 5.92cm hoog.

Met dit ontwerp is een goede balans bereikt tussen afmetingen en functionaliteit. Zo zou het voor het Bluetooth bereik nog beter geweest zijn om de lege antenne kant van de module volledig uit te laten steken. Nu is ervoor gekozen om een uitsnede te maken in de PCB en geen power planes er direct naast te laten lopen, hierdoor komen de Bluetooth prestaties hoogstwaarschijnlijk erg in de buurt van een uit te laten steken module zonder dat het zoveel ruimte inneemt.


Figuur 30

Verder is ervoor gekozen om de testpunten links onderin te plaatsen, hierdoor is het mogelijk om de GND van een probe aan het GND punt vast te klemmen en met de punt van de probe de andere testpunten af te gaan. Naast de testpunten en in de twee grote gaten onderin zal de RJ12 connector geplaatst worden. Volledig aan de bovenkant is de micro-USB poort te zien. Door deze tegenover elkaar te plaatsen kan de PCB aan de RJ12 connector in de P1 poort hangen en wanneer nodig van stroom worden voorzien via de micro-USB poort. Doordat deze twee connectoren tegenover elkaar geplaatst zijn blijven de stressen op de connectoren en kabels minimaal wanneer deze aangesloten zijn. Daarnaast is er zoals goed te zien is in Figuur 30 gekozen om componenten aan beide kanten van de PCB te plaatsen. Dit maakt het assembleren wel een stuk ingewikkelder maar bespaart enorm veel ruimte. Verder is aan de onderkant de J3 connector te zien. Dit is de 2x5 2.54mm smd footprint voor het debuggen van de microcontroller en het mogelijk toevoegen van functies door vier beschikbare GPIO pinnen.

https://www.ti.com/sitesearch/docs/universalsearch.tsp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

Mogelijk geschikte schakelende voeding ic.

http://mouser.componentsearchengine.com/pcb-libraries.php

DC/DC converter component

https://devzone.nordicsemi.com/f/nordic-q-a/53691/re-changing-the-uart-tx-rx-pins

Veranderen van de UART pinnen

MDBT42Q-512KV2

Wordt gebruikt als module met NRF52832 erop.

http://domoticx.com/p1-poort-slimme-meter-hardware/

Website met heel veel informatie over verschillende DSMR-standaarden en de p1 poort zelf.

https://opencircuit.nl/Blog/Slimme-meter-uitlezer

Voorbeeld slimme meter uitlezen

https://nl.mouser.com/ProductDetail/Texas-Instruments/TPS7A2533DRVR?qs=OTrKUuiFdkbvIrFjA0rssQ%3D%3D

Gebruikte LDO

https://www.ti.com/lit/ds/symlink/lm3671.pdf?ts=1631871038849&ref_url=https%253A%252F%252Fwww.google.com%252F

Schakelende voeding gebruikt in HomeWizzard P1 meter

http://ncepower.com/Upload/NCE60P02Ydatasheet-10382020261.pdf

P-channel mosfet gebruik in Homewizzard

https://www.nordicsemi.com/Nordic-Partners/3rd-party-modules

Modules met Nordic chips

https://aconno.de/products/acn52832/

NRF52832 module uit Duitsland met ingebouwde RGB led

https://nl.mouser.com/ProductDetail/Toshiba/SSM6P36TULF?qs=B6kkDfuK7%2FCXuFvKzbJMTQ%3D%3D

Dual p-channel mosfet ic

https://nl.mouser.com/ProductDetail/Nexperia/PMEG4005AESFYL?qs=Yna0arPQ0CT21It55ddDRA%3D%3D

Schottky diode low dropout voltage

https://nl.mouser.com/ProductDetail/Nexperia/PMEG3020EP115?qs=GcY6OjH1zdnlY%252B06tUqEyw%3D%3D

Een iets grotere Schottky diode

https://nl.mouser.com/ProductDetail/ROHM-Semiconductor/SML-E12P8WT86?qs=4kLU8WoGk0vBFbk40ZI0Fw%3D%3D

Goedkope groene led

https://nl.mouser.com/ProductDetail/Wurth-Elektronik/615006138421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

Female RJ12 connector gebruikt in het ontwerp

https://nl.mouser.com/ProductDetail/Molex/95501-6669?qs=KUIzHt%2Fe91nGEpACmwALwA%3D%3D

Andere female RJ12 connector

https://nl.mouser.com/ProductDetail/Texas-Instruments/TLV9101IDBVR?qs=P1JMDcb91o6ZLUyc%2FHtrGA%3D%3D

In het ontwerp gebruikte opamp als signaalomvormer

https://nl.mouser.com/ProductDetail/Toshiba/SSM6P36TULF?qs=B6kkDfuK7%2FCXuFvKzbJMTQ%3D%3D

Dual p-channel mosfet

https://nl.mouser.com/ProductDetail/Nexperia/NX7002AKAR?qs=rkhjVJ6%2F3EJRNheJHlWytQ%3D%3D

Single n-channel mosfet

https://nl.mouser.com/ProductDetail/Toshiba/SSM6N7002KFULF?qs=lhkzy8lC%252BStoJHMOsaa2bw%3D%3D

Dual n-channel mosfet

https://nl.mouser.com/ProductDetail/Wurth-Elektronik/150060VS55040?qs=8Aa6%252B7C6HEumg%252B0cJZzvA%3D%3D

Groene LED

https://nl.mouser.com/ProductDetail/Wurth-Elektronik/150060BS55040?qs=fAHHVMwC%252BbiEgEQkEQqtiA%3D%3D

Blauwe LED

https://nl.mouser.com/ProductDetail/Lumileds/L1MC-RGB0035000MP0?qs=l4Gc20tDgJJ2Q8oG8kKRKQ%3D%3D

RGB led

https://nl.mouser.com/ProductDetail/Molex/47589-0001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

In het ontwerp gebruikte micro-USB poort

https://nl.mouser.com/ProductDetail/Nexperia/NX3020NAK215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

Single n-channel Mosfet op voorraad

https://nl.mouser.com/ProductDetail/Nexperia/NX3008PBKW115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

Single p-channel Mosfet op voorraad

P1 poort slimme meter (hardware)

Figuur 31


Figuur 32

# Bibliografie

[1] | N. Nederland, "DSMR 5.0 datasheet," 26 2 2016. [Online]. Available: https://www.netbeheernederland.nl/_upload/Files/Slimme_meter_15_a727fce1f1.pdf.
[2] | N. Nederland, "DSMR 4.2 datasheet," 26 6 2016. [Online]. Available: https://www.netbeheernederland.nl/_upload/Files/Slimme_meter_15_32ffe3cc38.pdf. [Accessed 23 9 2021].
[3] | Nordic Semi, "3rd party modules/modems," [Online]. Available: https://www.nordicsemi.com/Nordic-Partners/3rd-party-modules. [Accessed 14 9 2021].
[4] | DomoticX, "P1 poort slimme meter (hardware)," [Online]. Available: http://domoticx.com/p1-poort-slimme-meter-hardware/. [Accessed 1 9 2021].

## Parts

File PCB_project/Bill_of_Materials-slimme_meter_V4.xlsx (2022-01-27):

Comment | Description | Designator | Footprint | LibRef | Quantity
1uF, 25V, 0603 |  | C1, C2 | CAPC1608X90X35LL10T15 | CMP-2006-02459-1 | 2
4.7uF, 35V, 0805 | Chip Multilayer Ceramic Capacitors for General Purpose, 0805, 4.7uF, X5R, 15%, 10%, 35V | C3 | FP-GRM219-0_15-0_1-IPC_B | CMP-06035-049019-1 | 1
PMEG3020EP,115 | Diode | D1 | SODFL4725X110N | PMEG3020EP,115 | 1
TPS7A2533DRVR | Integrated Circuit | IC2 | SON65P200X200X80-7N | TPS7A2533DRVR | 1
TLV9101IDBVR | Integrated Circuit | IC3 | SOT95P280X145-5N | TLV9101IDBVR | 1
95501-6669 | Connector | J1 | 95501-6669 | 95501-6669 | 1
47589-0001 | Right Angle Female Type AB Micro USB Connector, 30 V, 1.8 A, -30 to 85 degC, RoHS, Tape and Reel | J2 | MOLX-47589-0001_V | CMP-2000-05610-1 | 1
2x5_2.54mm_smd | Connector | J3 | 10129383910001ALF | 2x5_2.54mm_smd | 1
L1MC-RGB0035000MP0 | LED | LED1 | L1MCRGB0035000MP0 | L1MC-RGB0035000MP0 | 1
NX3020NAK,215 | MOSFET (N-Channel) | Q1, Q2, Q3, Q4 | SOT95P230X110-3N | NX3020NAK,215 | 4
NX3008PBKW,115 | MOSFET (P-Channel) | Q5, Q6 | SOT65P210X110-3N | NX3008PBKW,115 | 2
10KΩ, 1/10W, 0603 | Chip Resistor, 10 KOhm, +/- 1%, 100 mW, -55 to 155 degC, 0603 (1608 Metric), RoHS, Tape and Reel | R1, R2, R3, R14, R15, R16 | RESC1609X50X30NL8T20 | CMP-1666-00005-4 | 6
18Ω, 0.1W, 0603 |  | R9 | RESC1608X55X30ML15T15 | CMP-2000-00306-1 | 1
33Ω, 0.1W, 0603 |  | R10 | RESC1608X55X30ML15T15 | CMP-2000-00443-1 | 1
82Ω, 0.1W, 0603 |  | R11 | RESC1608X55X30LL15T15 | CMP-2000-00662-1 | 1
1MΩ, 1/10W, 0603 | RES Thick Film, 1MΩ, 5%, 0.1W, 200ppm/°C, 0603 | R12, R13 | FP-CRCW0603-e3-IPC_B | CMP-2000-03016-2 | 2
4.7KΩ, 1/10W, 0603 | Precision Thick Film Chip Resistor, 4.7 KOhm, +/- 1%, -55 to 155 degC, 0603 (1608 Metric), RoHS, Tape and Reel | R17, R18, R19 | RESC1608X55X30NL15T15 | CMP-1012-00586-3 | 3
1.5KΩ, 1/10W, 0603 |  | R20 | RESC1608X55X30ML15T15 | CMP-1012-00528-2 | 1

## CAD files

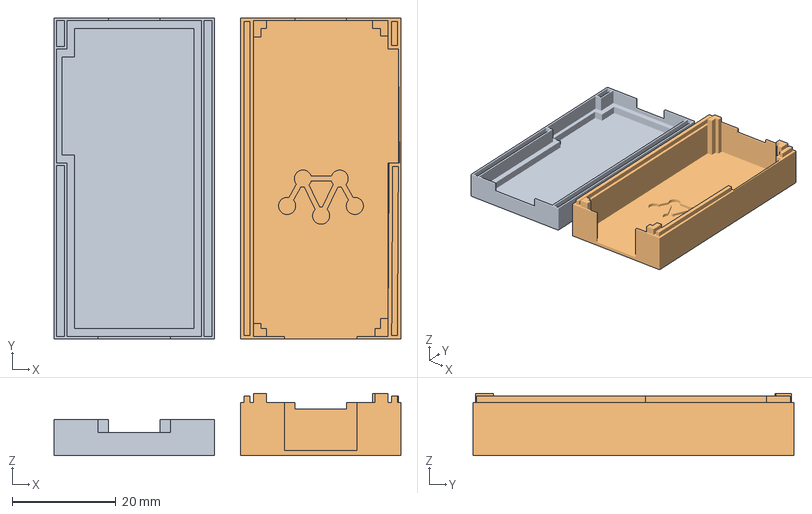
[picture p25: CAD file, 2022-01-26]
PCB_project/Smart meter case.3mf
67.0 x 62.0 x 12.0 mm

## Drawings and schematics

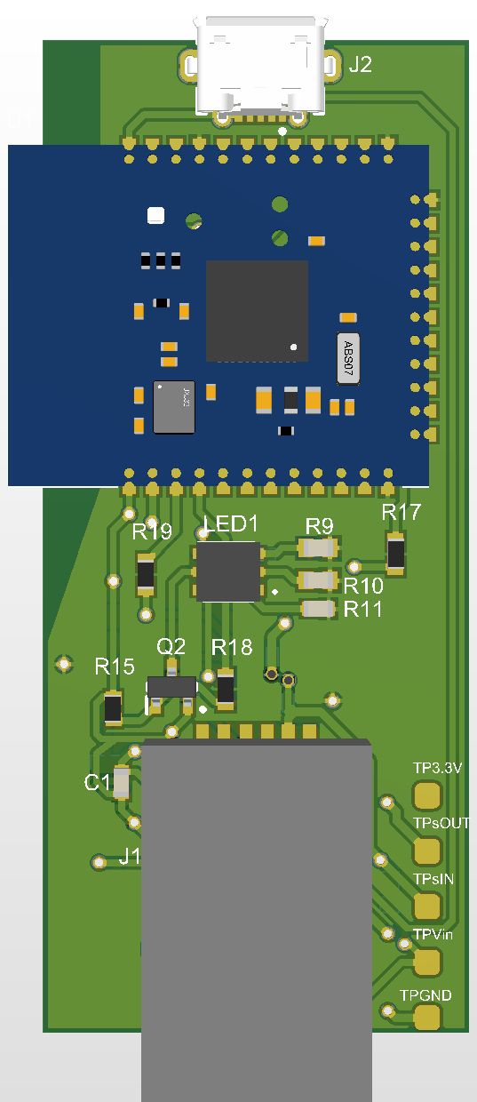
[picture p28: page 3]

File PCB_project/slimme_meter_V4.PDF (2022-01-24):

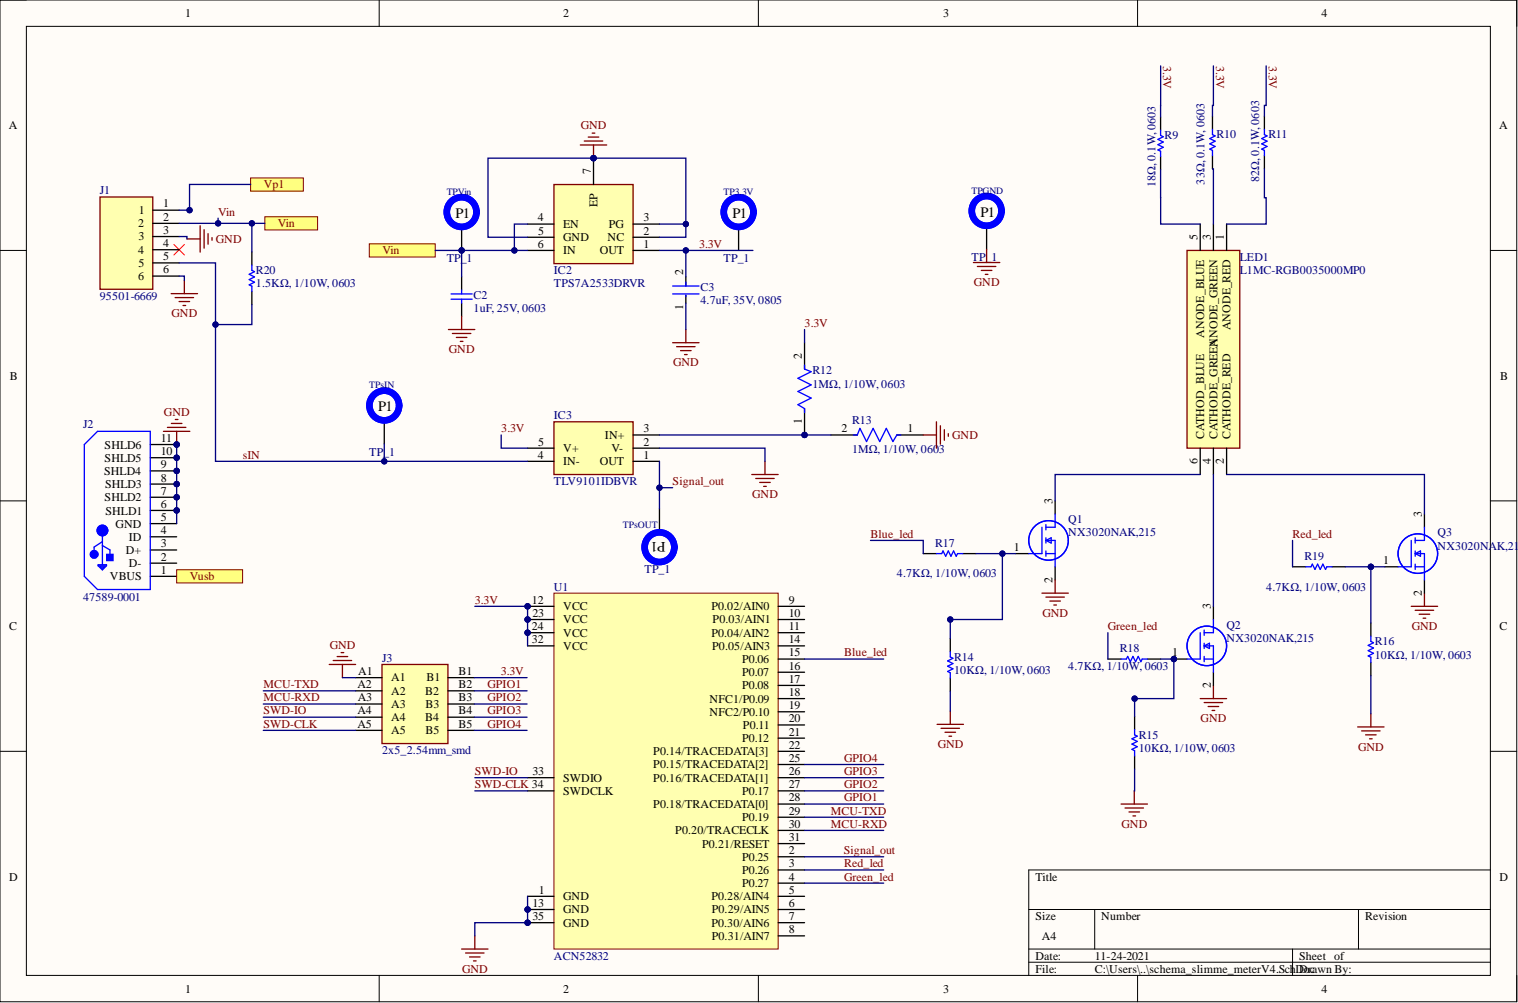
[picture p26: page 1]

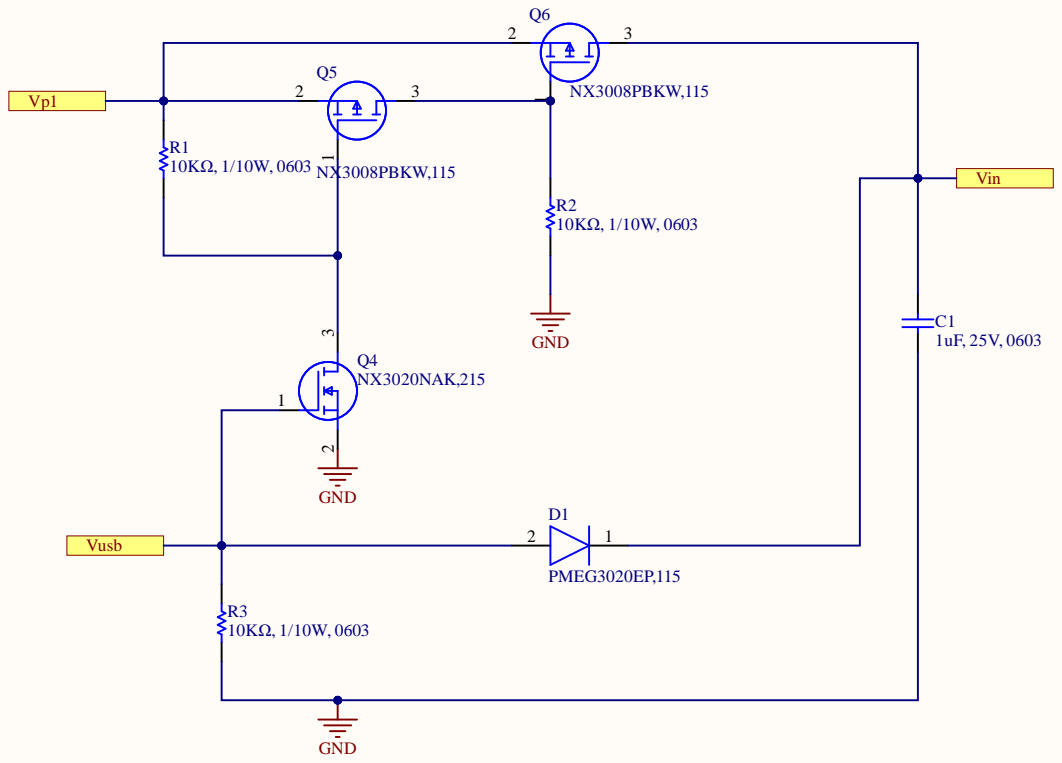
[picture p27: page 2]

Q4 NX3020NAK,215
